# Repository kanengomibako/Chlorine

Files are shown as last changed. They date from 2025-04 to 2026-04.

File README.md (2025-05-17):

# Chlorine
### STM32 Programmable Digital Effects Pedal
STM32マイコンを搭載した、プログラミング可能なデジタルエフェクターです。C言語またはC++で開発を行います。もちろんプログラム書き込み後は単体のエフェクターとして動作可能です。

旧機種 [Sodium](https://github.com/kanengomibako/Sodium) と比較すると、処理能力は2倍以上です。また、最大入出力音量増加・ノイズ低減・操作系強化・USBアップデート機能追加等、大幅にアップグレードされました。

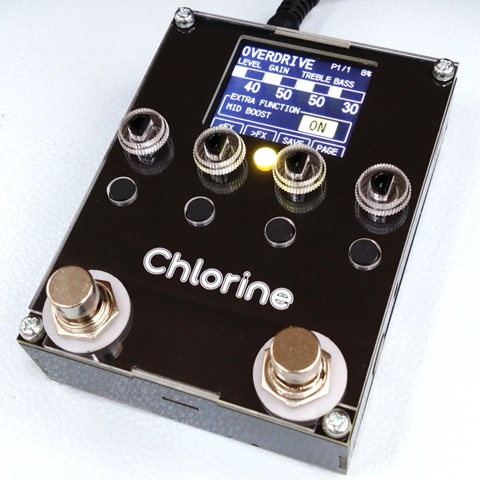
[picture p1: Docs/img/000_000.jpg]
Chlorine_pic


### 別途必要なもの
- DC9V（センターマイナス）出力のACアダプターで、0.5A以上の電流出力が可能なもの
> [!caution]
> 10V以上の電圧で連続使用しないでください。故障の原因となります。

- PC（Windows、macOS、Linux いずれも可、64bit推奨）<br/>※ 32bit環境では使用できる開発ソフトが限られます。
- STM32対応のデバッガ（プログラム書き込みやデバッグを行う機器）<br/>
	→ [デバッガ購入について](https://github.com/kanengomibako/Sodium/blob/main/Docs/005_%E3%83%87%E3%83%90%E3%83%83%E3%82%AC%E8%B3%BC%E5%85%A5%E3%81%AB%E3%81%A4%E3%81%84%E3%81%A6.md)
- PCとデバッガを接続するUSBケーブル
- デバッガとChlorine本体を接続するケーブル<br/>
	→ [コネクタ付コード 3P](https://akizukidenshi.com/catalog/g/gC-15384/) と [両端ロングピンヘッダー](https://akizukidenshi.com/catalog/g/g109055/) 等

### 各部の機能
- INPUT 端子：ギターや他の機器からの出力を接続します（ステレオ入力可）。
- OUTPUT 端子：アンプや他の機器の入力へ接続します（ステレオ出力可）。
- +9VDC 端子：ACアダプターを接続します。
- 各スイッチ・ロータリーエンコーダ：任意の機能をプログラミング可能です。サンプルプログラムの操作については[別ページ](Docs/000_初期プログラムについて.md)をご参照ください。
- MIDI 入力端子：他の機器からのMIDI信号を入力することができます（TRS MIDI）。
- Serial Wire Debug (SWD) 接続ピンソケット：デバッガのSWCLK、GND、SWDIOピンを、Chlorineのピンソケットへそれぞれ接続します。
- USB Type-C 入力端子：USB Type-Cケーブルを接続することができます。

### 資料
- [初期プログラムについて](Docs/000_初期プログラムについて.md)
- [デバッガ購入について](https://github.com/kanengomibako/Sodium/blob/main/Docs/005_%E3%83%87%E3%83%90%E3%83%83%E3%82%AC%E8%B3%BC%E5%85%A5%E3%81%AB%E3%81%A4%E3%81%84%E3%81%A6.md)
- [プログラム書き込み・デバッグ](Docs/001_プログラム書き込み・デバッグ.md)
- [マイコンの機能設定](Docs/003_マイコンの機能設定.md)
- [プログラミング概要](Docs/004_プログラミング概要.md)
- [Chlorine プログラム書込ツール](https://kanengomibako.github.io/pages/00361_Chlorine_WebUSBDFU.html)
- [開発記録](https://kanengomibako.github.io/pages/00364_chlorine.html)

エフェクトについては、旧機種Sodium用のページをご参照ください。基本的にはChlorineも同じプログラム内容です。

- [エフェクト種類管理（fx.cpp）について](https://github.com/kanengomibako/Sodium/blob/main/Docs/100_%E3%82%A8%E3%83%95%E3%82%A7%E3%82%AF%E3%83%88%E7%A8%AE%E9%A1%9E%E7%AE%A1%E7%90%86%EF%BC%88fx.cpp%EF%BC%89%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)

- [エフェクトファイル（fx_○○.hpp）について](https://github.com/kanengomibako/Sodium/blob/main/Docs/110_%E3%82%A8%E3%83%95%E3%82%A7%E3%82%AF%E3%83%88%E3%83%95%E3%82%A1%E3%82%A4%E3%83%AB%EF%BC%88fx_%E2%97%8B%E2%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)

- [各エフェクト説明目次](https://github.com/kanengomibako/Sodium/blob/main/Docs/200_%E5%90%84%E3%82%A8%E3%83%95%E3%82%A7%E3%82%AF%E3%83%88%E8%AA%AC%E6%98%8E%E7%9B%AE%E6%AC%A1.md)

| 主な仕様 |  |
| - | - |
| サンプリング周波数 | 48 kHz（44.1 kHz または 96 kHz に設定可能） |
| 内部演算 | 32 ビット浮動小数点 |
| AD、DA変換 | 24 ビット |
| レイテンシ | 1.2 ミリ秒（サンプルプログラム実行時） |
| 最大入力レベル | 2.0 Vrms (+8.2 dBu) |
| 入力インピーダンス | 1 MΩ |
| 最大出力レベル | 2.0 Vrms (+8.2 dBu) |
| 出力インピーダンス | 1 kΩ |
| バイパス | バッファード・バイパス（バイパス音もAD/DA変換されます） |
| コントロール | 押しボタンスイッチ付きロータリーエンコーダ × 4<br/>押しボタンスイッチ × 4　フットスイッチ × 2 |
| ディスプレイ | 1.77インチ 液晶ディスプレイ　カラー 160 × 128 ドット |
| インジケーター | 3色LED（直径5mm） |
| 接続端子 | INPUT端子　OUTPUT端子　電源入力端子　MIDI入力端子<br/>Serial Wire Debug (SWD) 接続ピンソケット　USB Type-C 入力端子 |
| 消費電流 | 180 mA |
| 外形寸法 | 幅 76 mm × 奥行 100 mm × 高さ 45 mm |
| 質量 | 200 g |

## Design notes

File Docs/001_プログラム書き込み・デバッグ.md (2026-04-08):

# プログラム書き込み、デバッグ

例として、サンプルプログラムの書き込み、デバッグまでの手順を説明します。

***

### 1. STM32CubeIDE、STM32CubeMXのインストール
STM32マイコンの統合開発環境として、[STM32CubeIDE](https://www.st.com/ja/development-tools/stm32cubeide.html)と[STM32CubeMX](https://www.st.com/ja/development-tools/stm32cubemx.html)をインストールします（32bitのOSには非対応）。ダウンロードに[myST](https://www.st.com/content/st_com/ja.html)への登録が必要です。初回起動時にWorkspace（作業フォルダ）を設定しますが、パスに全角文字が入らないようにしておきます。STM32CubeIDE未経験の方は、練習としてNucleo Boardを使ったLチカを先にされておくことをお勧めします。

- 参考ページ → [STM32CubeIDE 2.0.0 workflow tutorial](https://community.st.com/t5/stm32-mcus/stm32cubeide-2-0-0-workflow-tutorial/ta-p/864831)

***

### 2. 必要なファイルのダウンロード、コード出力、ビルド

- 下記URLからzipファイルをダウンロード・展開

  [https://github.com/kanengomibako/Chlorine/blob/main/Src/example/Chlorine_example_v0.2.zip](https://github.com/kanengomibako/Chlorine/blob/main/Src/example/Chlorine_example_v0.2.zip)

- Workspace（作業フォルダ）内に、新しく「Chlorine_example」というフォルダを作成

- Chlorine_example.iocをChlorine_exampleフォルダ内に移動

- STM32CubeMXを起動 → Other Projects から Chlorine_example.iocを読み込み → GENERATE CODE

  ※ バージョンが違うといったメッセージが表示された場合は、「Continue」を選択します。

  ※ 初回はファームウェアのダウンロード等があるため時間がかかります。

- ダウンロード・展開したファイルを移動
	- STM32H723VGTX_FLASH.ld → プロジェクトフォルダ内の同名ファイルに上書き
		
	- .cファイル　.cppファイル → Core/Src フォルダへ（main.c は上書き）
	
	- .hファイル　.hppファイル → Core/Inc フォルダへ
	
- STM32CubeIDEを起動 → File → STM32 Project Create/Import → STM32CubeMX/STM32CubeIDE Projectを選択 → Chlorine_exampleフォルダを選択

- プロジェクトを右クリックし、Convert to C++ → 金槌アイコンをクリックしてビルド

- common.h を編集すると時間設定等を行うことができます。

- fx.cpp を編集すると有効化するエフェクトを選択できます。

***

### 3. デバッガの接続、デバッグ
- デバッガのSWCLK、GND、SWDIOピンを、Chlorine側のピンソケットへそれぞれ接続

  ▼ Nucleo Board（Nucleo-64タイプ）を使う場合（左上のジャンパーを外しておく）

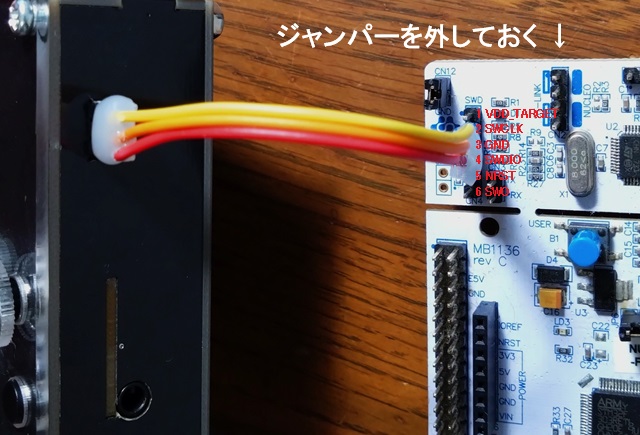
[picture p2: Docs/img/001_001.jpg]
デバッガーの接続
  

- 虫アイコンをクリック → Edit Configuration ウィンドウ → そのままOK

プログラムが書き込まれ、デバッグが開始されます。デバッグ画面では動作開始、一時停止等の操作を行うことができます。

サンプルプログラムの操作方法については、[初期プログラムについて](000_初期プログラムについて.md)のページをご参照ください。

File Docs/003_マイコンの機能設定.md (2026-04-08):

# マイコンの機能設定

iocファイルを開くと、STM32マイコンのピンや機能の設定を行うことができます。Chlorineでの設定内容について説明します。

~~2025年4月7日時点の最新STM32CubeMXソフトウェア（6.14）では、SAIの設定を行うことができません。iocファイルをテキストエディタで開き、「MxCube.Version=6.13.0」「MxDb.Version=DB.6.0.130」と編集すると旧バージョンになります。開くときに新しいバージョンに移行する（Migrate）かダイアログが出るので、旧バージョンのままの Continue を選択します。~~2026年4月8日時点の最新STM32CubeMXソフトウェア（6.17.0）では、修正されています。

***

### 1. System Core
＜キャッシュを有効化、MPUの設定＞
- System Core → CORTEX_M7
	- CPU ICache : Enabled
	- CPU DCache : Enabled
	- MPU Control Mode : Background Region Privileged accesses only + MPU Disabled during ～
	- MPU Region : Enabled
	- MPU Region Base Address : 0x30000000
	- MPU Region Size : 512B
	- MPU SubRegion Disable : 0x0
	- MPU TEX field level : level 0
	- MPU Access Permission : ALL ACCESS PERMITTED
	- MPU Instruction Access : ENABLE
	- MPU Shareability Permission : ENABLE
	- MPU Cacheable Permission : DISABLE
	- MPU Bufferable Permission : ENABLE

＜クロック源として外部水晶振動子を使用、レギュレータの設定＞
- System Core → RCC
	- High Speed Clock (HSE) : Crystal/Ceramic Resonator
	- Parameter Settings タブ
	  - Power Regulator Voltage Scale : Power Regulator Voltage Scale 0

***
### 2. Timers
＜ディスプレイの輝度調整のため、PWMを有効化＞
- Timers → TIM1
  - Channel4 : PWM Generation CH4
  - Parameter Settings タブ Counter Settings
    - Prescaler (PSC - 16 bits value) : 0
    - Counter Period (AutoReload Resister - 16 bits value) : 1023

***

### 3. Connectivity

＜EEPROM接続のため、I2C2を有効化＞

- Connectivity → I2C2
  - I2C : I2C
  - Parameter Settings タブ
    - I2C Speed Mode : Fast Mode
    - I2C Speed Frequency (KHz) : 400
- PB10、PB11 を使うようにピン設定

＜ディスプレイ接続のため、SPI2を有効化＞

- Connectivity → SPI2
  - Mode : Half-Duplex Master
  - Parameter Settings タブ
    - Data Size : 8 Bits
    - Prescaler (for Baud Rate) : 32
- PB13、PB15 を使うようにピン設定

＜MIDI信号送受信のため、USART3を有効化＞

- Connectivity → USART3
  - Mode : Asynchronous
  - Parameter Settings タブ
    - Baud Rate : 31250 Bits/s
    - Stop Bits : 1
    - MSB First : Disable
  - NVIC Settings タブ
    - USART3 global interrupt にチェック
- PD8 、PD9 を使うようにピン設定
- System Core → NVIC（割り込みの優先度を設定）
  - USART3 global interrupt の Preemption Priority : 5

***

### 3. Multimedia 
＜オーディオコーデック接続のため、SAI1を有効化＞
- Multimedia → SAI1
  - SAI A
    - Mode : Master with Master Clock Out
    - I2S/PCM Protocolにチェック
  - SAI B
    - Mode : Synchronous Slave
    - I2S/PCM Protocolにチェック
- Parameter Settings タブ
  - SAI A
    - Audio Mode : Master Receive
    - Data Size : 32 Bits
    - Audio Frequency : 48 KHz
    - Fifo Threshold : Half Full
  - SAI B
    - Audio Mode : Slave Transmit
    - Data Size : 32 Bits
    - Fifo Threshold : Half Full
- DMA Settings タブ
  - Addボタンで追加 → DMA Request [SAI1_A]  Priority [Very High]
    - Mode : Circular
    - Data Width (Peripheral) : Word
    - Data Width (Memory) : Word
  - Addボタンで追加 → DMA Request [SAI1_B]  Priority [Very High]
    - Mode : Circular
    - Data Width (Peripheral) : Word
    - Data Width (Memory) : Word
- PE2、PE3、PE4、PE5、PE6 を使うようにピン設定

***

### 4. Trace and Debug

＜デバッガーの接続方式を設定＞

- Trace and Debug → DEBUG
  - Debug : Serial Wire

***

### 5. Clock Configuration
Clock Configuration タブで下図の通り設定

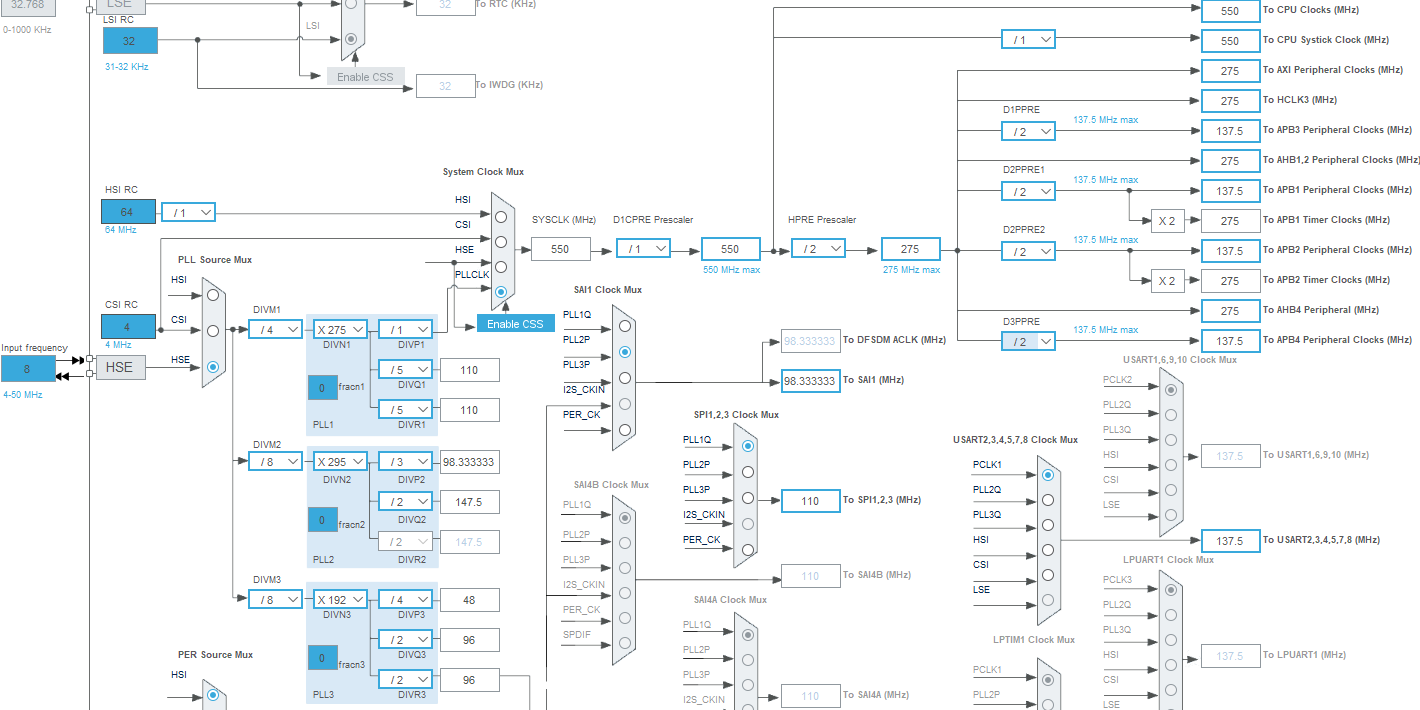
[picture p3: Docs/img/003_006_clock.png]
clock
 

実際のオーディオサンプリングレートは、SAIクロックを2の累乗数で割った数となるため、98.333 MHz ÷ 2048 ＝ 48014.32 Hz です。48kHzから少しズレますが、プログラム上の定義をこの値にすれば実用上問題はありません（#define SAMPLING_FREQ 48014.32f）。

オーディオサンプリングレートを44.1kHzにする場合は、DIVN2とDIVP2を [×271] [/3] とすると誤差が少ないです（90.333 MHz ÷ 2048 ＝ 44108.07 Hz）。

***

### 6. スイッチ・LED（GPIO）
- Pinout viewでGPIO_Input、GPIO_Outputを設定

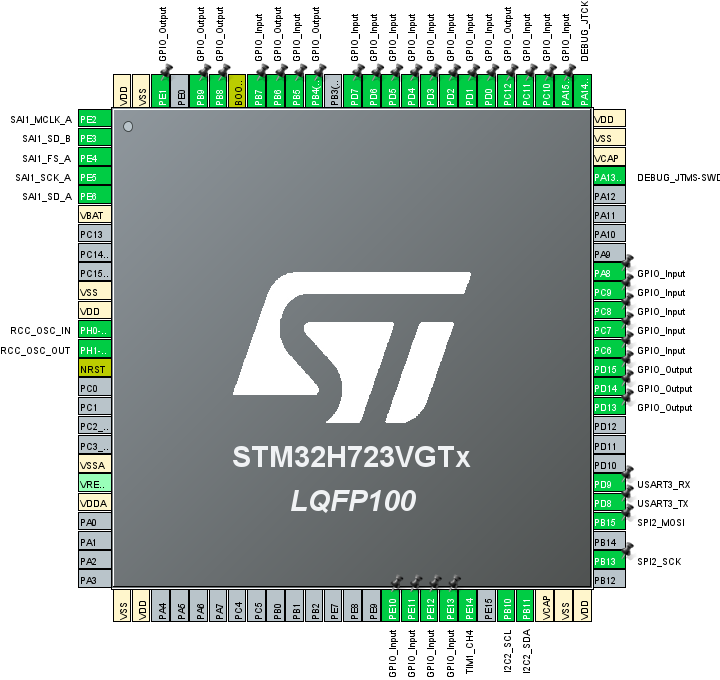
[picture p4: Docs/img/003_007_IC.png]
IC
 

- System Core → GPIO からUser Labelを設定

User Labelの定義は、main.h に自動出力されます。（例：#define LED_B_Pin GPIO_PIN_12）

| ピン | ユーザーラベル |
| ---- | ---- |
| PA8 | RE2A |
| PA15 | RE2B |
| PB4 | LED_G |
| PB5 | RE0A |
| PB6 | LED_R |
| PB7 | RE0B |
| PB8 | M0 |
| PB9 | M1 |
| PC6 | SW9 |
| PC7 | RE3B |
| PC8 | SW3 |
| PC9 | RE3A |
| PC10 | SW5 |
| PC11 | SW4 |
| PC12 | LED_B |
| PD0 | SW2 |
| PD1 | SW8 |
| PD2 | SW1 |
| PD3 | RE1A |
| PD4 | SW7 |
| PD5 | RE1B |
| PD6 | SW6 |
| PD7 | SW0 |
| PD13 | LCD_RS |
| PD14 | LCD_RES |
| PD15 | LCD_CS |
| PE1 | CODEC_RST |
| PE10 | HARDWARE_VERSION0 |
| PE11 | HARDWARE_VERSION1 |
| PE12 | HARDWARE_VERSION2 |
| PE13 | HARDWARE_VERSION3 |

***

### 7. 最適化設定

高速動作のため、コンパイラの最適化設定を変更します。iocファイルの編集ではなく、メニューバーから設定します。
- Project → Properties → C/C++ Build → Settings → Tool Settings タブ
	- C言語
		- MCU GCC Compiler → Optimization → Optimization level [Optimize Most (-O3)]
	- C++
		- MCU G++ Compiler → Optimization → Optimization level [Optimize Most (-O3)]

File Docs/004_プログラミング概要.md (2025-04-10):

# プログラミング概要

### 1. ハードウェア
Chlorineの回路を簡略化した図を示します。

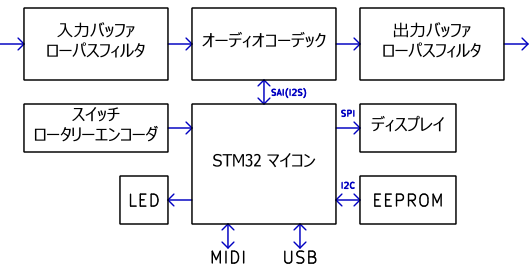
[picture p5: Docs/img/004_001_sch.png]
簡略図
 

入力信号は、オーディオコーデックでアナログ→デジタル変換され（ADC）、マイコンへ送られます。マイコンで信号処理し送られたデータは、デジタル→アナログ変換され（DAC）出力されます。このデータ送受信の方式は I2S（Inter-IC Sound）フォーマットと呼ばれるもので、この通信を行うのが SAI ペリフェラルです。

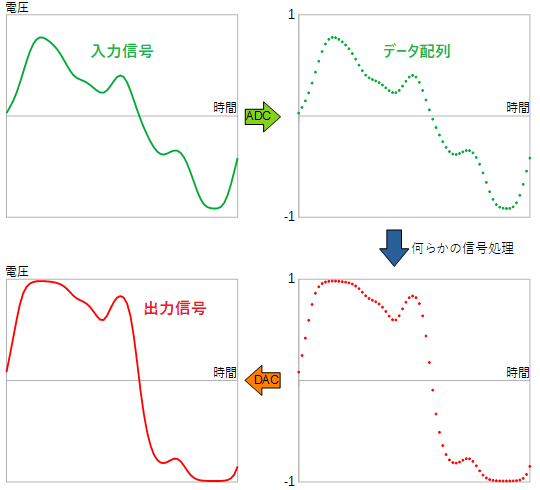
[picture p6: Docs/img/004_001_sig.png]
波形
 

機器に入力された音声信号は時間と電圧の関係として表されます。これを一定時間ごとにサンプリング（電圧読み取り）し、データ配列としてコンピュータに取り込みます。このサンプルデータに何らかの処理を施すことで、エフェクトをかけるということになります。

オーディオサンプリングレート44.1kHzの場合は、1秒間に44100個<sup>※</sup>のデータサンプルを送受信します。効率よく処理するため、ある程度まとまったサンプル数で処理を行います。このサンプルの個数がブロックサイズです。（※ 正確には、LchとRchで1組として44100組、88200個）

マイコンからディスプレイへのデータ送信はSPI（Serial Peripheral Interface）、EEPROMのデータ保存・読込はI2C（Inter-Integrated Circuit）と呼ばれる通信方式です。

***

### 2. 動作の流れ

- メインループ
	
	まず main.c の main 関数が実行されますが、その中で各機能の初期化後、mainLoop 関数が繰り返し実行されます。Chlorineでは、ここで主にディスプレイ表示の更新を行っています。
	※ main.c に直接主なコードを書いてもよいのですが、誤って USER CODE 以外の部分に書いてしまうとコード自動生成時に消去されるので、user_main.cpp という別ファイルに分けています。
	
- SAI 割り込み
	
	SAI で常にデータの入出力を行っていますが、ブロックサイズごとに割り込みが起こるようになっています（3. 信号処理詳細 参照）。この割り込み時にエフェクト処理やスイッチ状態の読み取りを行っています。

メインループ 

デュアルコアではないので、同時並行して処理を進めることはできません。基本は信号処理（割り込み）を行い、空いた時間にメインループの処理が進みます。もし信号処理に時間がかかりすぎれば、メインループ側の処理が進まないのでディスプレイ表示の更新がうまくいかないことになります。

***

### 3. 信号処理詳細

SAI用の送受信バッファ配列サイズはブロックサイズの4倍となっています。中身は「Lch前半・後半、Rch前半・後半」で、データの順序はLR交互（L・R・L・R...）ですが、ここではLRで1組として考えます。

データ前半の受信が終わると user_main.cpp にある HAL_SAI_RxHalfCpltCallback 関数が、後半の受信が終わると HAL_SAI_RxCpltCallback 関数が呼び出されます。下図のような流れです。

SAI 

例えば音量を上げるエフェクトの場合は、この割り込み内でデータ数値を増加させればいいということになります。

割り込みの間隔は、ブロックサイズ16、サンプリングレート48kHzの場合 16 / 48 = 0.33 ms（ミリ秒）です。処理遅延はこの2倍発生し、さらにオーディオコーデックIC自体の遅延があるため、全体の遅延（レイテンシ）は約1.2msとなっています。

- DMAについて

  DMA（Direct Memory Access）はデータ送受信の繰り返しを自動で行ってくれる便利な機能です。ただしSTM32H7では、DMA対象データの配置先の指定、MPU（Memory Protection Unit）の設定が必要となります。
  
  - 参考ページ → [STM32H7でキャッシュ一貫性を保持したDMA転送(Memory-to-Peripheral)](https://www.keshikan.net/gohantabeyo/?p=563)
  
    ※ MPUの設定は、[マイコンの機能設定](003_マイコンの機能設定.md)で行うことが可能です。

***

### 4. スイッチ

前述の通り、SAI 割り込みは定期的に起こります。スイッチが押されているかどうかの読み取り（HAL_GPIO_ReadPin 関数）も割り込み内で行います。

読み取りはそこまで頻繁に行う必要はないため、割り込み1では左端スイッチ、割り込み2では中央左スイッチ...というように読み取るスイッチを順番に入れ替えています。（フットスイッチはタップテンポの精度に関係してくるため、毎回読み取りを行っています。）

スイッチのチャタリングによる誤検出防止のため、一定時間連続で押されている判定があった場合に処理を行います。判定時間は #define SHORT_PUSH_MSEC 20 といった具合に設定しています。

***

### 5. ロータリーエンコーダ

一般にロータリーエンコーダの出力波形は下図のようになります。

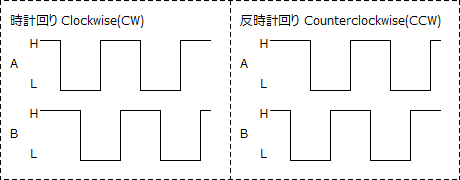
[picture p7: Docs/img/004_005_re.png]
RE


SAI 割り込みのときにHとLを読み取り、4パターンで記録しておきます。

- A: H　B: H → パターン0
- A: L　B: H → パターン1
- A: L　B: L → パターン2
- A: H　B: L → パターン3

そして、前回のパターンから現在のパターンへの変化によって時計回りと反時計回りを判定します。

※ ロータリーエンコーダの種類によってはクリック位置での出力規定が異なるため、別の判定へと修正が必要となる場合があります。

- パターン0からパターン1 または パターン2からパターン3 :  時計回り
- パターン0からパターン3 または パターン2からパターン1 :  反時計回り

***

### 6. データ保存

USBアップデートでフラッシュメモリを書き換えるとなると、ユーザーデータを外部に保存しておく必要があります。そのため、Chlorineでは外部EEPROMを使用しています。データ保存は優先度を高くする必要がないため、メインループ内で処理を行っています。EEPROMは100万回以上書き換えできますが、プログラミングのミスで繰り返し書き込みが発生するような状態が起きると寿命が縮まってしまうため、注意が必要です。

***

### 7. MIDI

MIDIメッセージの受信時に割り込み（HAL_UART_RxCpltCallback 関数）が発生しますが、現状は特に機能を持たせていません。

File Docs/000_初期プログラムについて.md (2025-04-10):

# 初期プログラムについて

動作確認用初期プログラムとして、数種類のエフェクトを切り替えて実行可能なサンプルプログラムが入っています。

### 表示

- 最上部

  エフェクト名、パラメータページ番号／最大パラメータページ数、CPU使用率%

  ※入出力が過大な音量でクリッピングが起きたとき、「L R i o」といった文字が点滅表示されます。それぞれ「左 右 入力 出力」という意味です。

- 中段上

  エフェクトパラメータ名と数値

- 中段下

  右フットスイッチに割り当てられている機能の表示

- 下段

  押しボタンスイッチに割り当てられている機能の表示

### 操作方法
- スイッチ付きロータリーエンコーダ（ノブを押すとスイッチとして動作）
	- ロータリーエンコーダを回転：パラメータの増減
	
	- スイッチを押しながらロータリーエンコーダを回転：パラメータ10ずつ増減（パラメータ数値に下線が表示）

- 左端スイッチ：前エフェクトに切替

- 中央左スイッチ：次エフェクトに切替

- 中央右スイッチ：データ保存（右上に「STORED!」と点滅表示）

- 右端スイッチ：エフェクトパラメータが5つ以上の場合、ページ切替

- 左フットスイッチ：エフェクトのオン／オフ切替

- 右フットスイッチ：ブースト機能のオン／オフ切替 または タップテンポ

### 輝度調整
右フットスイッチを押した状態で起動すると、画面の輝度（Brightness）が設定できます。起動後も右フットスイッチを押したまま、右端スイッチと左端スイッチで調整します。右フットスイッチを離すと、自動で輝度データが保存されます。

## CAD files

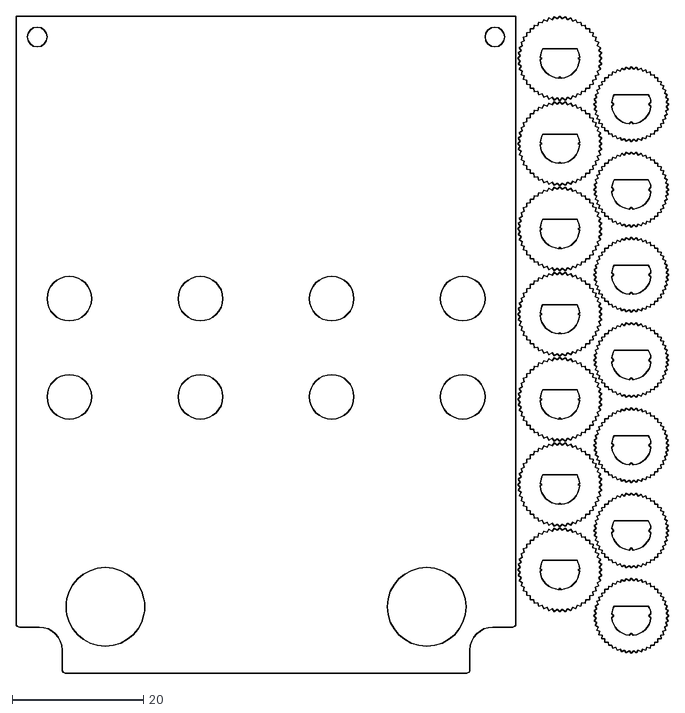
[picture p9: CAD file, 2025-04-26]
KiCad/enclosure/chlorineBox-acryl-Edge_Cuts.dxf
99.5 x 100.2

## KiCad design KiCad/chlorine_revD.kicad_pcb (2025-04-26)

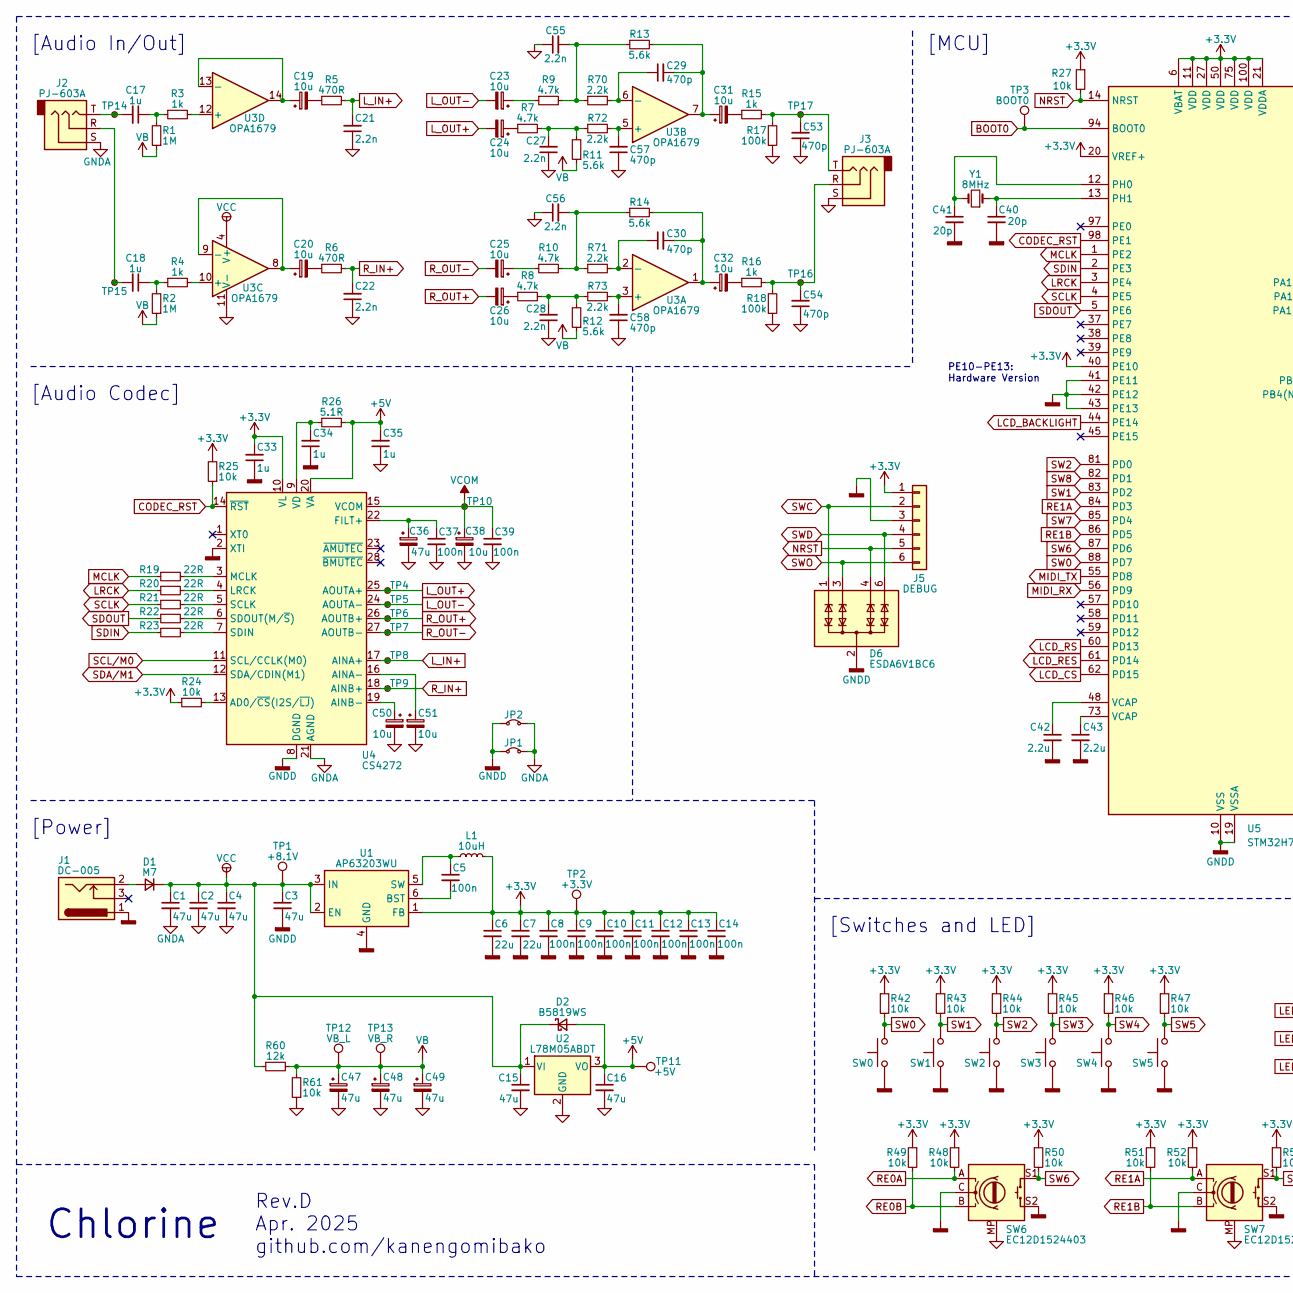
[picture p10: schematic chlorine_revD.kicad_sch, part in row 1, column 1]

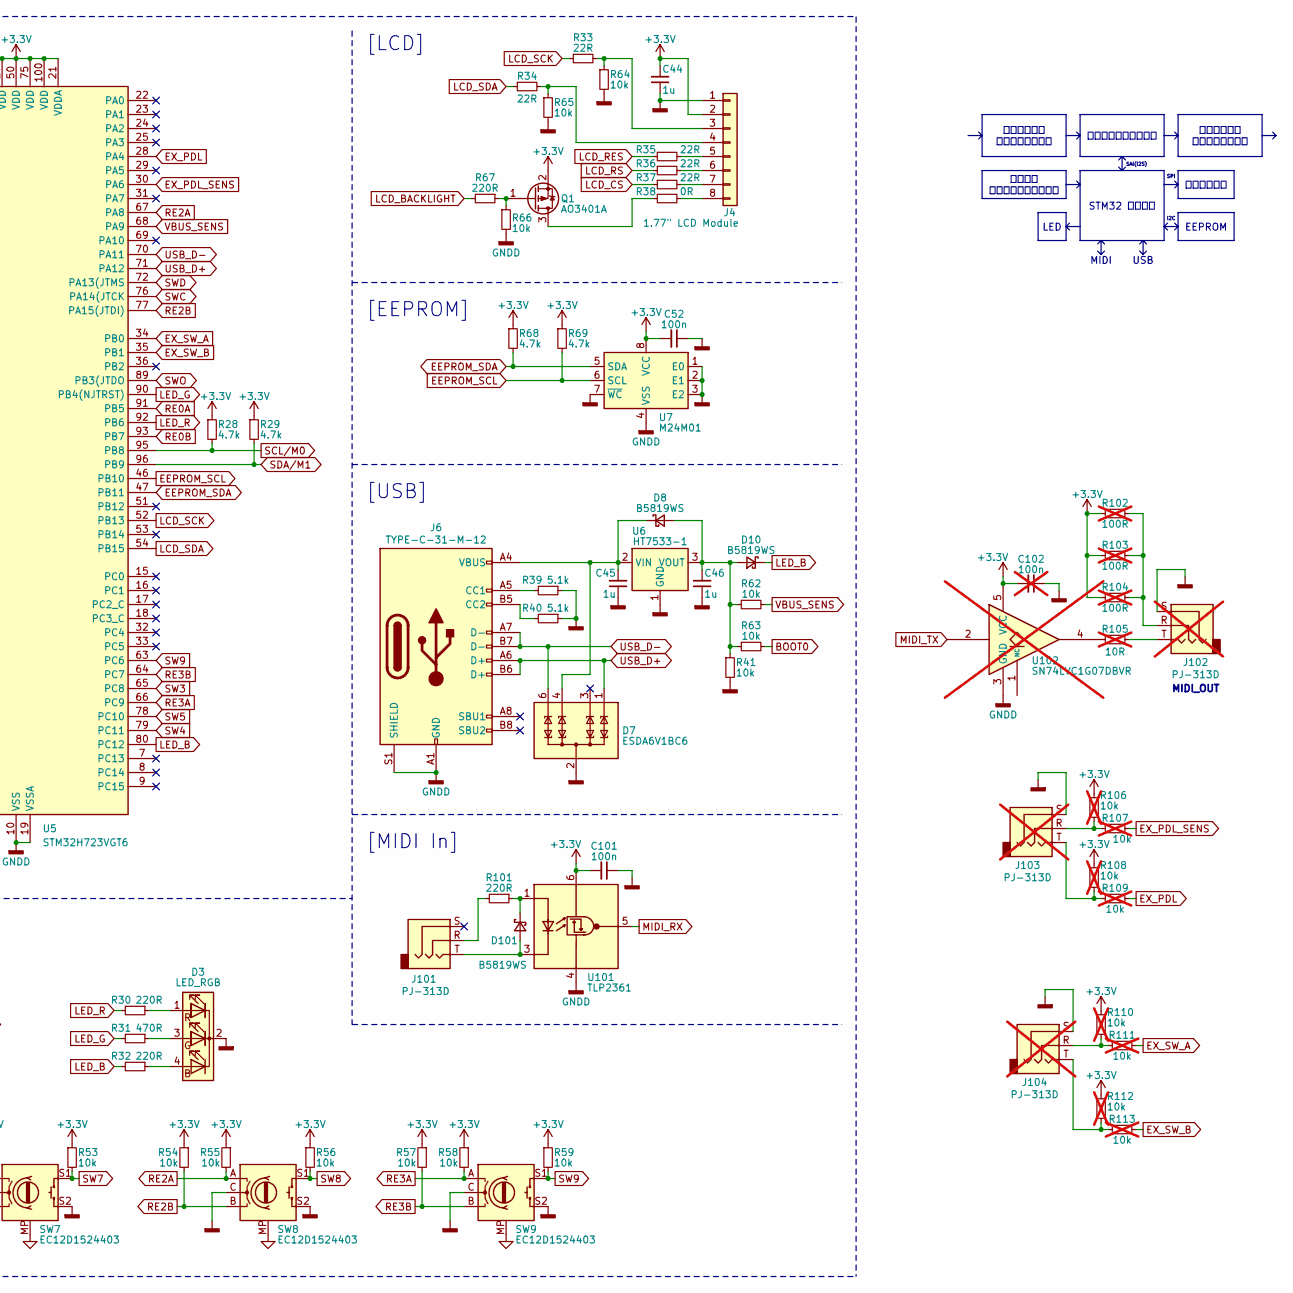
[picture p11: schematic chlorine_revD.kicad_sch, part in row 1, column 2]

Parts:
C1, C2, C3, C4, C15, C16: 47u; C_1206_3216Metric; MPN C96123
C5, C8, C9, C10, C11, C12, C13, C14, C37, C39, C52, C101: 100n; C_0603_1608Metric; MPN C14663
C6, C7: 22u; C_1206_3216Metric; MPN C12891
C17, C18: 1u; C_1210_3225Metric; MPN C569895
C19, C20, C23, C24, C25, C26, C31, C32, C38, C50, C51: 10u; CP_EIA-3216-10_Kemet-I; MPN C7171
C21, C22, C27, C28, C55, C56: 2.2n; C_0805_2012Metric; MPN C28260
C29, C30, C53, C54, C57, C58: 470p; C_0603_1608Metric; MPN C85979
C33, C34, C35, C44, C45, C46: 1u; C_0603_1608Metric; MPN C15849
C36, C47, C48, C49: 47u; CP_EIA-3528-15_AVX-H; MPN C22036
C40, C41: 20p; C_0603_1608Metric; MPN C1648
C42, C43: 2.2u; C_1206_3216Metric; MPN C50254
C102: 100n; C_0603_1608Metric; MPN C14663; not fitted
D1: M7; D_SMA; MPN C95872
D2, D8, D10, D101: B5819WS; my_D_SOD-323; MPN C64886
D3: LED_RGB; my_LED_5mm_RGB_mirror
D6, D7: ESDA6V1BC6; my_SOT-23-6_rotate; MPN C2912546
J1: DC-005; my_DC_Jack
J2, J3: PJ-603A; MPN C309273
J4: 1.77" LCD Module; LCD_Display_1.77inch
J5: DEBUG; PinSocket_1x06_P2.54mm_Horizontal
J6: TYPE-C-31-M-12; USB_C_TYPE-C-31-M-12; MPN C165948
J101: PJ-313D; PJ-313D_HOOYA; MPN C668608
J102, J103, J104: PJ-313D; PJ-313D_HOOYA; MPN C668608; not fitted
JP1, JP2: JP; AD_GND_Jumper
L1: 10uH; L_7.3x7.3_H3.5; MPN C2827354
Q1: AO3401A; SOT-23_rotate; MPN C15127
R1, R2: 1M; R_0603_1608Metric; MPN C22935
R3, R4, R15, R16: 1k; R_0603_1608Metric; MPN C21190
R5, R6, R31: 470R; R_0603_1608Metric; MPN C23179
R7, R8, R9, R10, R28, R29, R68, R69: 4.7k; R_0603_1608Metric; MPN C23162
R11, R12, R13, R14: 5.6k; R_0603_1608Metric; MPN C23189
R17, R18: 100k; R_0603_1608Metric; MPN C25803
R19, R20, R21, R22, R23, R33, R34, R35, R36, R37: 22R; R_0603_1608Metric; MPN C23345
R24, R25, R27, R41, R42, R43, R44, R45, R46, R47, R48, R49, R50, R51, R52, R53, R54, R55, R56, R57, R58, R59, R61, R62, R63, R64, R65, R66: 10k; R_0603_1608Metric; MPN C25804
R26: 5.1R; R_0603_1608Metric; MPN C25197
R30, R32, R67, R101: 220R; R_0603_1608Metric; MPN C22962
R38: 0R; R_1206_3216Metric; MPN C17888
R39, R40: 5.1k; R_0603_1608Metric; MPN C23186
R60: 12k; R_0603_1608Metric; MPN C22790
R70, R71, R72, R73: 2.2k; R_0603_1608Metric; MPN C4190
R102, R103, R104: 100R; R_1206_3216Metric; MPN C17901; not fitted
R105: 10R; R_1206_3216Metric; MPN C17903; not fitted
R106, R107, R108, R109, R110, R111, R112, R113: 10k; R_0603_1608Metric; MPN C25804; not fitted
SW0: SW0; my_SW_PUSH_12mm_narrow
SW1: SW1; my_SW_PUSH_12mm_narrow
SW2: SW2; my_SW_PUSH_12mm_narrow
SW3: SW3; my_SW_PUSH_12mm_narrow
SW4: SW4; spst_momentary_sw_foot
SW5: SW5; spst_momentary_sw_foot
SW6, SW7, SW8, SW9: EC12D1524403
TP1: +8.1V; my_TestPoint_1.2mm
TP2: +3.3V; my_TestPoint_1.2mm
TP3: BOOT0; my_TestPoint_1.2mm
TP4: L_OUT+; my_TestPoint_1.2mm
TP5: L_OUT-; my_TestPoint_1.2mm
TP6: R_OUT+; my_TestPoint_1.2mm
TP7: R_OUT-; my_TestPoint_1.2mm
TP8: L_IN+; my_TestPoint_1.2mm
TP9: R_IN+; my_TestPoint_1.2mm
TP10: VCOM; my_TestPoint_1.2mm
TP11: +5V; my_TestPoint_1.2mm
TP12: VB_L; my_TestPoint_1.2mm
TP13: VB_R; my_TestPoint_1.2mm
TP14: L_IN; my_TestPoint_1.2mm
TP15: R_IN; my_TestPoint_1.2mm
TP16: R_OUT; my_TestPoint_1.2mm
TP17: L_OUT; my_TestPoint_1.2mm
U1: AP63203WU; my_SOT-23-6_rotate; MPN C780769
U2: L78M05ABDT; my_DPAK_TO-252-2; MPN C58069
U3: OPA1679; TSSOP-14_4.4x5mm_P0.65mm_rotate; MPN C2057264
U4: CS4272; TSSOP-28_4.4x9.7mm_P0.65mm_rotate
U5: STM32H723VGT6; LQFP-100_14x14mm_P0.5mm_rotate
U6: HT7533-1; SOT-89-3-rotate; MPN C14289
U7: M24M01; SOIC-8_3.9x4.9mm_P1.27mm_rotate
U101: TLP2361; SO-5_4.4x3.6mm_P1.27mm_rotate; MPN C107626
U102: SN74LVC1G07DBVR; my_SOT-23-5_rotate; MPN C7394020; not fitted
Y1: 8MHz; Crystal_SMD_5032-2Pin_5.0x3.2mm; MPN C115962

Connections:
+3.3V: C6.1, C7.1, C8.1, C9.1, C10.1, C11.1, C12.1, C13.1, C14.1, C33.2, C44.2, C52.2, C101.2, C102.2, J4.2, J5.1, L1.2, Q1.2 (S), R24.1, R25.2, R27.1, R28.1, R29.1, R42.1, R43.1, R44.1, R45.1, R46.1, R47.1, R48.1, R49.1, R50.1, R51.1, R52.1, R53.1, R54.1, R55.1, R56.1, R57.1, R58.1, R59.1, R68.1, R69.1, R102.2, R103.2, R104.2, R106.1, R108.1, R110.1, R112.1, TP2.1, U1.1 (FB), U4.10 (VL), U5.6 (VBAT), U5.11 (VDD), U5.20 (VREF+), U5.21 (VDDA), U5.27 (VDD), U5.40 (PE10), U5.50 (VDD), U5.75 (VDD), U5.100 (VDD), U7.8 (VCC), U101.6 (VDD), U102.5 (VCC)
+5V: C16.1, C35.2, D2.2 (A), R26.2, TP11.1, U2.3 (VO), U4.20 (VA)
BOOT0: R63.2, TP3.1, U5.94 (BOOT0)
CODEC_RST: R25.1, U4.14 (~RST), U5.98 (PE1)
EEPROM_SCL: R69.2, U5.46 (PB10), U7.6 (SCL)
EEPROM_SDA: R68.2, U5.47 (PB11), U7.5 (SDA)
EX_PDL: R109.2, U5.28 (PA4)
EX_PDL_SENS: R107.2, U5.30 (PA6)
EX_SW_A: R111.2, U5.34 (PB0)
EX_SW_B: R113.2, U5.35 (PB1)
GNDA: C1.2, C2.2, C4.2, C15.2, C16.2, C21.1, C22.1, C27.1, C28.1, C35.1, C36.2, C37.2, C38.2, C39.2, C47.2, C48.2, C49.2, C50.2, C51.2, C53.1, C54.1, C55.1, C56.1, C57.1, C58.1, J2.S, J3.S, JP1.2 (B), JP2.2 (B), R17.1, R18.1, R61.1, SW6.MP, SW7.MP, SW8.MP, SW9.MP, U2.2 (GND), U3.11 (V-), U4.21 (AGND); also elsewhere on the board
GNDD: C3.2, C6.2, C7.2, C8.2, C9.2, C10.2, C11.2, C12.2, C13.2, C14.2, C33.1, C34.1, C40.2, C41.2, C42.2, C43.2, C44.1, C45.1, C46.1, C52.1, C101.1, C102.1, D3.2 (K), D6.2 (COM), D6.5 (COM), D7.2 (COM), D7.5 (COM), J1.1, J4.1, J5.3, J6.A1 (GND), J6.A12 (GND), J6.B1 (GND), J6.B12 (GND), J6.S1 (SHIELD), J102.S, J103.S, J104.S, JP1.1 (A), JP2.1 (A), R39.1, R40.1, R41.2, R64.2, R65.2, R66.2, SW0.1, SW1.1, SW2.1, SW3.1, SW4.1, SW5.1, SW6.C, SW6.S2, SW7.C, SW7.S2, SW8.C, SW8.S2, SW9.C, SW9.S2, U1.4 (GND), U4.2 (XTI), U4.8 (DGND), U5.10 (VSS), U5.19 (VSSA), U5.26 (VSS), U5.41 (PE11), U5.42 (PE12), U5.43 (PE13), U5.49 (VSS), U5.74 (VSS), U5.99 (VSS), U6.1 (GND), U7.1 (E0), U7.2 (E1), U7.3 (E2), U7.4 (VSS), U7.7 (~WC), U101.4 (GND), U102.3 (GND)
LCD_BACKLIGHT: R67.2, U5.44 (PE14)
LCD_CS: R37.1, U5.62 (PD15)
LCD_RES: R35.1, U5.61 (PD14)
LCD_RS: R36.1, U5.60 (PD13)
LCD_SCK: R33.1, U5.52 (PB13)
LCD_SDA: R34.1, U5.54 (PB15)
LED_B: D10.1 (K), R32.2, U5.80 (PC12)
LED_G: R31.2, U5.90 (PB4(NJTRST))
LED_R: R30.2, U5.92 (PB6)
LRCK: R20.1, U5.3 (PE4)
L_IN+: C21.2, R5.2, TP8.1, U4.17 (AINA+)
L_OUT+: C24.2, TP4.1, U4.25 (AOUTA+)
L_OUT-: C23.2, TP5.1, U4.24 (AOUTA-)
MCLK: R19.1, U5.1 (PE2)
MIDI_RX: U5.56 (PD9), U101.5 (VO)
MIDI_TX: U5.55 (PD8), U102.2
NRST: D6.4 (TVS3), J5.5, R27.2, U5.14 (NRST)
unnamed: C17.1, R1.2, R3.1
unnamed: C17.2, J2.T, TP14.1
unnamed: C18.1, R2.2, R4.1
unnamed: C18.2, J2.R, TP15.1
unnamed: C19.2, R5.1
unnamed: C20.2, R6.1
unnamed: C23.1, R9.1
unnamed: C24.1, R7.1
unnamed: C25.1, R10.1
unnamed: C26.1, R8.1
unnamed: C27.2, R7.2, R11.2, R72.1
unnamed: C28.2, R8.2, R12.2, R73.1
unnamed: C29.2, C31.1, R13.2, U3.7
unnamed: C30.2, C32.1, R14.2, U3.1
unnamed: C31.2, R15.1
unnamed: C32.2, R16.1
unnamed: C42.1, U5.48 (VCAP)
unnamed: C43.1, U5.73 (VCAP)
unnamed: C53.2, J3.T, R15.2, R17.2, TP17.1
unnamed: C54.2, J3.R, R16.2, R18.2, TP16.1
unnamed: C55.2, R9.2, R13.1, R70.1
unnamed: C56.2, R10.2, R14.1, R71.1
unnamed: D1.2 (A), J1.2
unnamed: D3.4 (BA), R32.1
unnamed: D3.3 (GA), R31.1
unnamed: D3.1 (RA), R30.1
unnamed: C45.2, D7.4 (TVS3), D8.1 (K), J6.A4 (VBUS), J6.A9 (VBUS), J6.B4 (VBUS), J6.B9 (VBUS), U6.2 (VIN)
unnamed: C46.2, D8.2 (A), D10.2 (A), R41.1, R62.1, R63.1, U6.3 (VOUT)
unnamed: D101.2 (A), J101.T, U101.3 (K)
unnamed: D101.1 (K), R101.1, U101.1 (A)
unnamed: J4.3, R33.2, R64.1
unnamed: J4.4, R34.2, R65.1
unnamed: J4.5, R35.2
unnamed: J4.6, R36.2
unnamed: J4.7, R37.2
unnamed: J4.8, R38.2
unnamed: J6.A5 (CC1), R39.2
unnamed: J6.B5 (CC2), R40.2
unnamed: J101.R, R101.2
unnamed: J102.R, R102.1, R103.1, R104.1
unnamed: J102.T, R105.1
unnamed: J103.R, R106.2, R107.1
unnamed: J103.T, R108.2, R109.1
unnamed: J104.R, R110.2, R111.1
unnamed: J104.T, R112.2, R113.1
unnamed: Q1.3 (D), R38.1
unnamed: Q1.1 (G), R66.1, R67.1
unnamed: R105.2, U102.4
unnamed: C5.2, U1.6 (BST)
unnamed: C5.1, L1.1, U1.5 (SW)
unnamed: C58.2, R73.2, U3.3 (+)
unnamed: C30.1, R71.2, U3.2 (-)
unnamed: C57.2, R72.2, U3.5 (+)
unnamed: C29.1, R70.2, U3.6 (-)
unnamed: R4.2, U3.10 (+)
unnamed: C20.1, U3.8, U3.9 (-)
unnamed: R3.2, U3.12 (+)
unnamed: C19.1, U3.13 (-), U3.14
unnamed: R24.2, U4.13 (AD0/~CS(I2S/~LJ))
unnamed: C51.1, U4.16 (AINA-)
unnamed: C50.1, U4.19 (AINB-)
unnamed: C36.1, C37.1, U4.22 (FILT+)
unnamed: R20.2, U4.4 (LRCK)
unnamed: R19.2, U4.3 (MCLK)
unnamed: R21.2, U4.5 (SCLK)
unnamed: R23.2, U4.7 (SDIN)
unnamed: R22.2, U4.6 (SDOUT(M/~S))
unnamed: C34.2, R26.1, U4.9 (VD)
unnamed: C41.1, U5.12 (PH0), Y1.2
unnamed: C40.1, U5.13 (PH1), Y1.1
RE0A: R48.2, SW6.A, U5.91 (PB5)
RE0B: R49.2, SW6.B, U5.93 (PB7)
RE1A: R52.2, SW7.A, U5.84 (PD3)
RE1B: R51.2, SW7.B, U5.86 (PD5)
RE2A: R55.2, SW8.A, U5.67 (PA8)
RE2B: R54.2, SW8.B, U5.77 (PA15(JTDI))
RE3A: R58.2, SW9.A, U5.66 (PC9)
RE3B: R57.2, SW9.B, U5.64 (PC7)
R_IN+: C22.2, R6.2, TP9.1, U4.18 (AINB+)
R_OUT+: C26.2, TP6.1, U4.26 (AOUTB+)
R_OUT-: C25.2, TP7.1, U4.27 (AOUTB-)
SCLK: R21.1, U5.4 (PE5)
SCL/M0: R28.2, U4.11 (SCL/CCLK(M0)), U5.95 (PB8)
SDA/M1: R29.2, U4.12 (SDA/CDIN(M1)), U5.96 (PB9)
SDIN: R23.1, U5.2 (PE3)
SDOUT: R22.1, U5.5 (PE6)
SW0: R42.2, SW0.2, U5.88 (PD7)
SW1: R43.2, SW1.2, U5.83 (PD2)
SW2: R44.2, SW2.2, U5.81 (PD0)
SW3: R45.2, SW3.2, U5.65 (PC8)
SW4: R46.2, SW4.2, U5.79 (PC11)
SW5: R47.2, SW5.2, U5.78 (PC10)
SW6: R50.2, SW6.S1, U5.87 (PD6)
SW7: R53.2, SW7.S1, U5.85 (PD4)
SW8: R56.2, SW8.S1, U5.82 (PD1)
SW9: R59.2, SW9.S1, U5.63 (PC6)
SWC: D6.1 (TVS1), J5.2, U5.76 (PA14(JTCK)
SWD: D6.6 (TVS4), J5.4, U5.72 (PA13(JTMS)
SWO: D6.3 (TVS2), J5.6, U5.89 (PB3(JTDO)
USB_D+: D7.1 (TVS1), J6.A6 (D+), J6.B6 (D+), U5.71 (PA12)
USB_D-: D7.6 (TVS4), J6.A7 (D-), J6.B7 (D-), U5.70 (PA11)
VB: C47.1, C48.1, C49.1, R1.1, R2.1, R11.1, R12.1, R60.2, R61.2, TP12.1, TP13.1
VBUS_SENS: R62.2, U5.68 (PA9)
VCC: C1.1, C2.1, C3.1, C4.1, C15.1, D1.1 (K), D2.1 (K), R60.1, TP1.1, U1.2 (EN), U1.3 (IN), U2.1 (VI), U3.4 (V+)
VCOM: C38.1, C39.1, TP10.1, U4.15 (VCOM)

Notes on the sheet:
[Power]
I2C
Chlorine
[MIDI In]
MIDI_OUT
SAI(I2S)
出力バッファ ローパスフィルタ
STM32 マイコン
[LCD]
オーディオコーデック
EEPROM
LED
Rev.D Apr. 2025 github.com/kanengomibako
スイッチ ロータリーエンコーダ
ディスプレイ
[Switches and LED]
SPI
USB
[MCU]
MIDI
入力バッファ ローパスフィルタ
[EEPROM]
[Audio In/Out]
[Audio Codec]
[USB]
PE10-PE13: Hardware Version

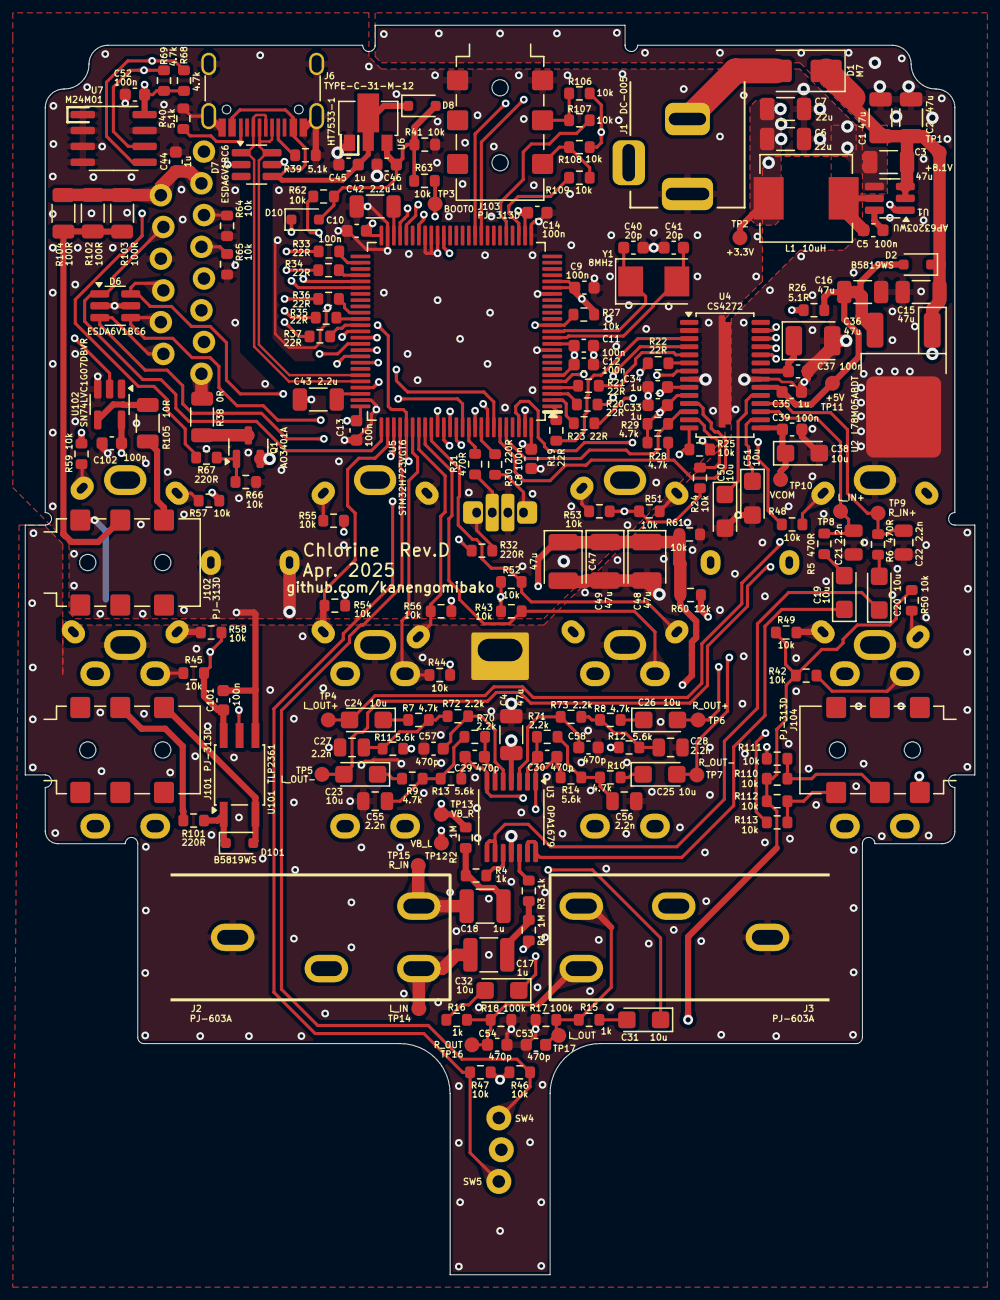
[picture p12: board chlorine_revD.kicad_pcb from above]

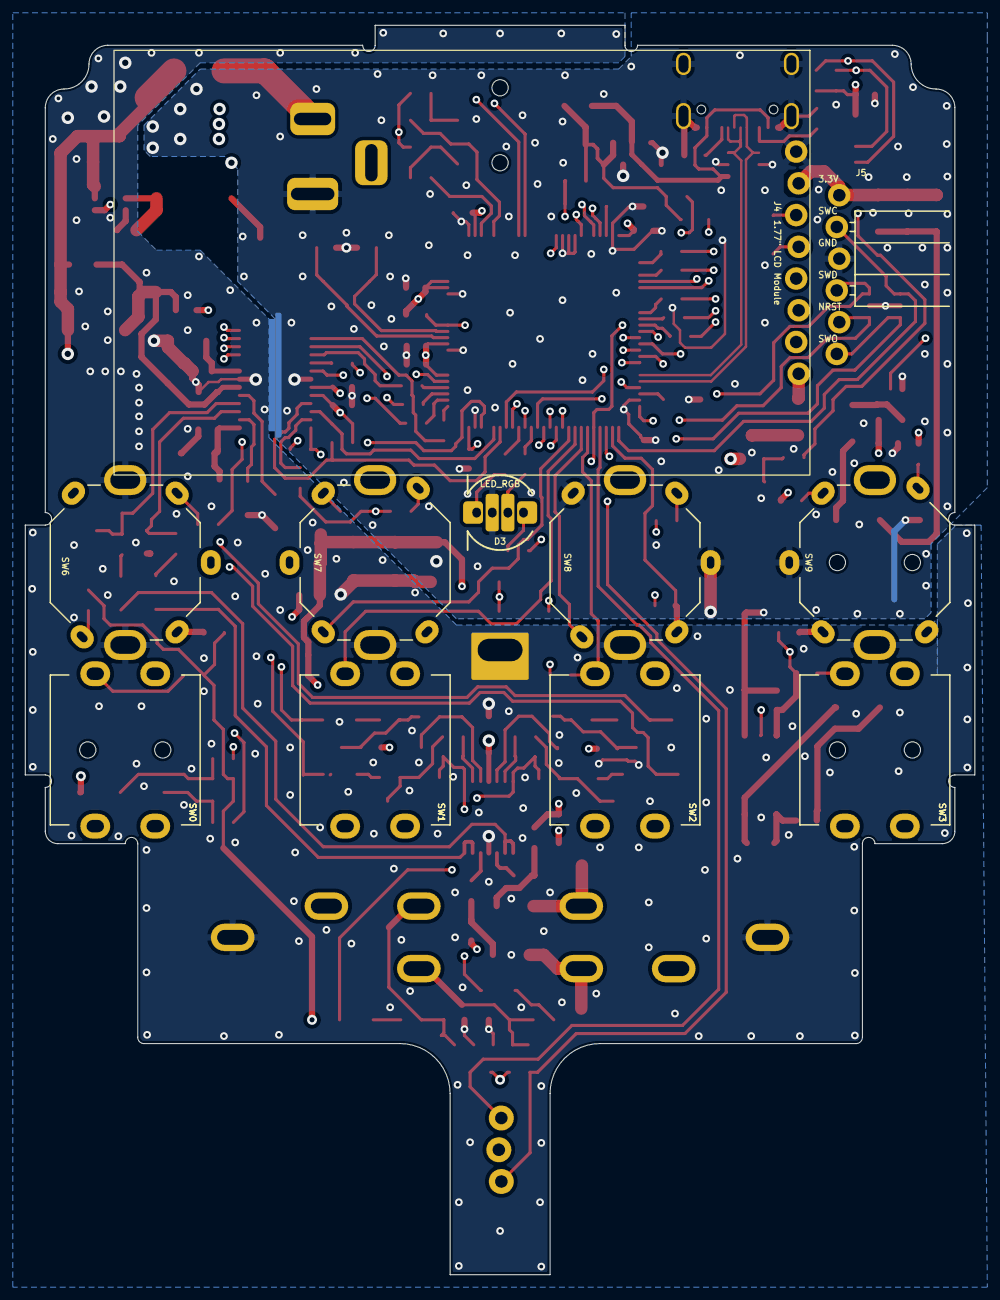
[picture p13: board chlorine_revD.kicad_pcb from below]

Board: 4 copper layers, 76.0 x 100.0 mm, 206 parts (12 on the bottom side), 134 nets.

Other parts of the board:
*: m; MountingHole_3.2mm_M3_ISO7380_Pad

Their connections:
GNDA: *.1; also elsewhere on the board

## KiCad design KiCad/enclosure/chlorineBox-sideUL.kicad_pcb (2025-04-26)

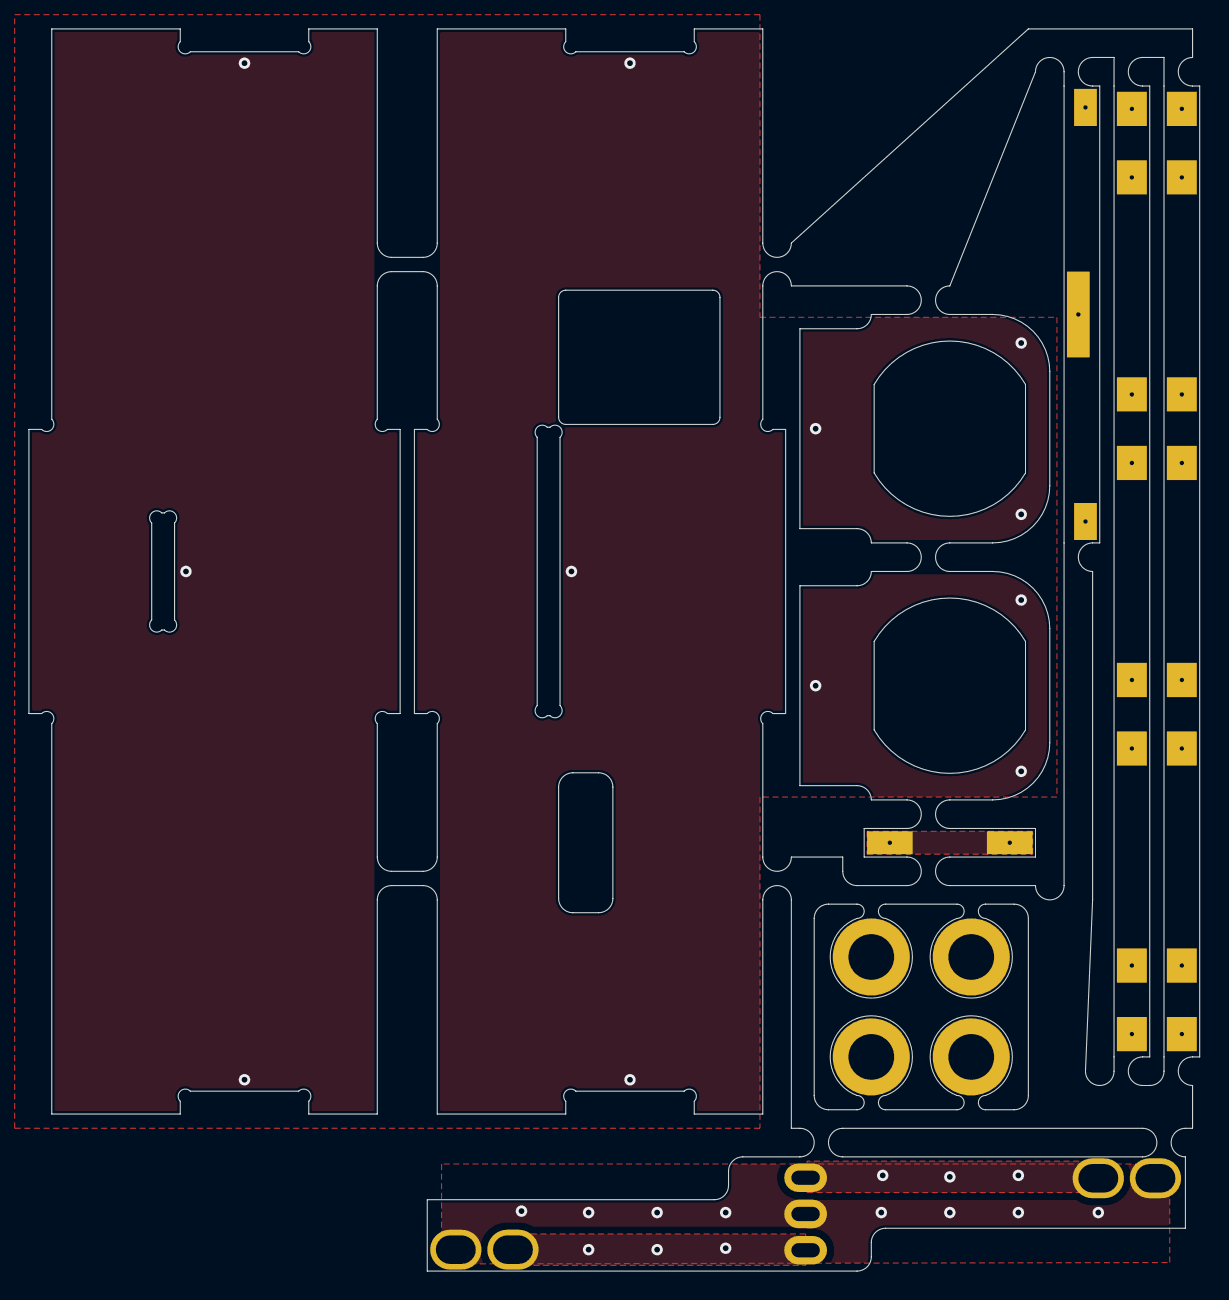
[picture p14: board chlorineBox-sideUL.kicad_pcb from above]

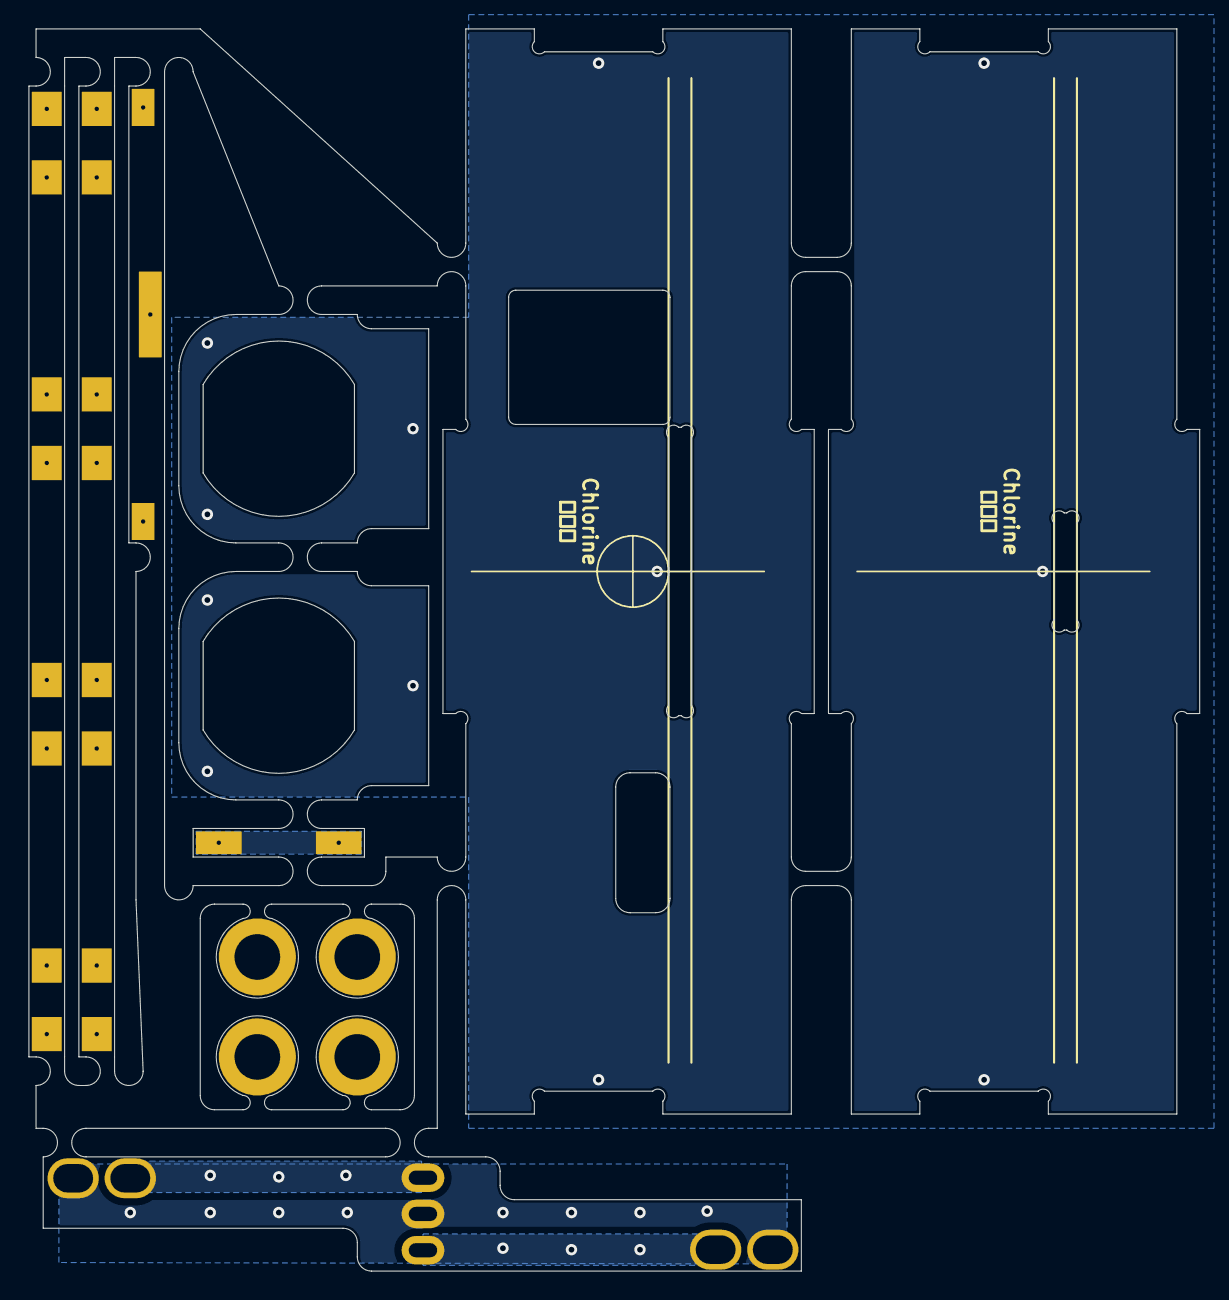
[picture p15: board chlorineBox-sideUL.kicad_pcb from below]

Board: 2 copper layers, 82.0 x 87.0 mm, 3 parts (3 on the bottom side), 3 nets, no tracks yet.

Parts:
J143: SWpin; PinHeader_1x03_P2.54mm_Vertical
SW5, SW6: sw; my_conn

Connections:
GND: J143.2, SW5.2, SW6.2
unnamed: J143.1, SW6.1
unnamed: J143.3, SW5.1

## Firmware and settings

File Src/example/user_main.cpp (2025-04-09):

#include "common.h"
#include "user_main.h"
#include "main.h"
#include "display.hpp"
#include "fx.hpp"
#include "eeprom.hpp"

extern SAI_HandleTypeDef hsai_BlockA1;
extern SAI_HandleTypeDef hsai_BlockB1;
extern TIM_HandleTypeDef htim1;
extern UART_HandleTypeDef huart3;

// DMA用バッファ配列 RAM_D2に置く
#define __ATTR_RAM_D2  __attribute__ ((section(".RAM_D2"))) __attribute__ ((aligned (4)))
int32_t RxBuffer[BLOCK_SIZE*4] __ATTR_RAM_D2 = {}; // 音声信号受信バッファ配列 Lch前半 Lch後半 Rch前半 Rch後半
int32_t TxBuffer[BLOCK_SIZE*4] __ATTR_RAM_D2 = {}; // 音声信号送信バッファ配列

uint32_t callbackCount = 0; // I2Sの割り込みごとにカウントアップ タイマとして利用
extern uint32_t cpuUsageCycleMax[]; // CPU使用サイクル数
const float i2sInterruptInterval = (float)BLOCK_SIZE / SAMPLING_FREQ; // I2Sの割り込み間隔時間

// スイッチ短押し、スイッチ長押し、ステータス情報表示時間のカウント数
const uint32_t shortPushCount = 1 + SHORT_PUSH_MSEC / (8 * 1000 * i2sInterruptInterval); // 1つのスイッチは8回に1回の読取のため8をかける
const uint32_t longPushCount = 1 + LONG_PUSH_MSEC / (8 * 1000 * i2sInterruptInterval);
const uint32_t statusDispCount = 1 + STATUS_DISP_MSEC / (1000 * i2sInterruptInterval);

bool fxOn = false; // エフェクトオン・オフ状態
bool exOn = false; // EX機能オン・オフ状態
string fxName = ""; // 現在のエフェクト名 11文字まで
string fxExFuncName = "TAP TEMPO"; // 現在のエフェクトのEX機能名 9文字まで
uint16_t fxColor = 0; // 現在のエフェクトLED色 RGB565
string fxParamName[20] = {}; // エフェクトパラメータ名 LEVEL, GAIN等
int16_t fxParam[20] = {}; // 現在のエフェクトパラメータ数値
string fxParamStr[20] = {}; // 現在のエフェクトパラメータ数値 文字列
int16_t fxParamMax[20] = {}; // エフェクトパラメータ最大値
int16_t fxParamMin[20] = {}; // エフェクトパラメータ最小値

//uint8_t fxParamNum = 0; // エフェクトパラメータ 現在何番目か ※0から始まる
uint8_t fxParamNumMax = 0; // エフェクトパラメータ数 最大値
uint8_t fxPage = 0; // エフェクトパラメータページ番号

uint8_t fxNum = 0; // 現在のエフェクト番号 ※0から始まる
int8_t fxChangeFlag = 0; // エフェクト種類変更フラグ 次エフェクトへ: 1 前エフェクトへ: -1

// 処理が重いエフェクトの場合、画面描画が遅くなる→画面描画が完了するまでエフェクトが切り替わらないようにする
uint8_t fxDispCpltFlag = 0; // エフェクト画面描画完了フラグ メインループ2回でエフェクト切替可能

string statusStr = PEDAL_NAME; // ステータス表示文字列

float tapTime = 0.0f; // タップテンポ入力時間 ms

int8_t re[5] = {};      // ロータリーエンコーダの状態 5番目re[4]は予備
int8_t last_re[5] = {}; // 前回のロータリーエンコーダの状態

const uint8_t fxNameXY[2] = {0,0};   // エフェクト名 表示位置
const uint8_t fxPageXY[2] = {110,0}; // エフェクトパラメータ ページ 表示位置
const uint8_t statusXY[2] = {110,10}; // ステータス 表示位置
const uint16_t percentXY[2] = {140,0}; // 処理時間% 表示位置
const uint8_t fxParamNameXY[6][2] = {{0,20},{39,20},{79,20},{119,20},{0,0},{0,0}}; // エフェクトパラメータ名表示位置
const uint8_t fxParamBarXY[6][2] = {{0,32},{39,32},{79,32},{119,32},{0,0},{0,0}}; // エフェクトパラメータバー表示位置
const uint8_t fxParamStrXY[6][2]  = {{2,49},{41,49},{81,49},{121,49},{0,0},{0,0}}; // エフェクトパラメータ数値表示 左端の文字位置

const uint8_t exFuncXY[2] = {9, 87}; // EX機能名称 表示位置
const uint8_t tapmsXY[2] = {69,87}; // タップテンポ ms 表示位置
const uint8_t tapbpmXY[2] = {111,87}; // タップテンポ bpm 表示位置

uint8_t clipDetect[4] = {}; // 入出力クリップ検出用 Lin Rin Lout Rout

bool saveDataFlag = false; // データ保存実行フラグ

uint16_t brightness[11] = {32,45,64,91,128,181,256,362,512,724,1024}; // LCD 明るさ
int8_t brightnessNum = 10; // LCD 明るさ段階数値 0～10

uint8_t midiRecievedBuf; // MIDI受信バッファ

void loadScreen() // 画面固定部分表示
{
  ST7735_FillScreen(ST7735_BLACK);

  // パラメーターバー枠表示
  for (int i = 0; i < 4; i++) ST7735_DrawLineX(40*i, 38+40*i, 32, ST7735_WHITE);
  for (int i = 0; i < 4; i++) ST7735_DrawLineX(40*i, 38+40*i, 46, ST7735_WHITE);
  for (int i = 0; i < 4; i++) ST7735_DrawLineY(0+40*i, 33, 45, ST7735_WHITE);
  for (int i = 0; i < 4; i++) ST7735_DrawLineY(38+40*i, 33, 45, ST7735_WHITE);

  // EX機能 枠表示
  ST7735_WriteString(9, 72, "EXTRA FUNCTION", Font_7x10, ST7735_WHITE, ST7735_BLACK);
  ST7735_DrawLineX(4, 7, 76, ST7735_WHITE);
  ST7735_DrawLineX(95, 154, 76, ST7735_WHITE);
  ST7735_DrawLineX(4, 154, 104, ST7735_WHITE);
  ST7735_DrawLineY(3, 77, 103, ST7735_WHITE);
  ST7735_DrawLineY(155, 77, 103, ST7735_WHITE);

  // ボタン名表示
  ST7735_WriteString(9, 115, "<FX", Font_7x10, ST7735_WHITE, ST7735_BLACK);
  ST7735_WriteString(49, 115, ">FX", Font_7x10, ST7735_WHITE, ST7735_BLACK);
  ST7735_WriteString(87, 115, "SAVE", Font_7x10, ST7735_WHITE, ST7735_BLACK);
  ST7735_WriteString(127, 115, "PAGE", Font_7x10, ST7735_WHITE, ST7735_BLACK);

  // ボタン枠表示
  for (int i = 0; i < 4; i++) ST7735_DrawLineX(2+40*i, 36+40*i, 110, ST7735_WHITE);
  for (int i = 0; i < 4; i++) ST7735_DrawLineX(2+40*i, 36+40*i, 127, ST7735_WHITE);
  for (int i = 0; i < 4; i++) ST7735_DrawLineY(1+40*i, 111, 126, ST7735_WHITE);
  for (int i = 0; i < 4; i++) ST7735_DrawLineY(37+40*i, 111, 126, ST7735_WHITE);
}

void dispBar(uint8_t i, int16_t param, int16_t min, int16_t max) // エフェクトパラメータバー表示
{
  uint8_t bar;

  // 割合を計算 ※ゼロ除算を除外
  if (max - min != 0) bar = 37 * (param - min) / (max- min);
  else bar = 0;

  for (int j = 33; j <= 45; j++)
  {
    ST7735_DrawLineX(40*i + 1, 40*i + bar, j, fxColor);
    ST7735_DrawLineX(40*i + bar + 1, 40*i + 37, j, ST7735_BLACK);
  }
}

void mainInit() // <<<<<<<<<<<<<<<<<<<<<<<<<<<<<<<<<<<<<<<<<<<最初に1回のみ行う処理
{
  // Denormalized numbers（非正規化数）を0として扱うためFPSCRレジスタ変更
  asm("VMRS r0, FPSCR");
  asm("ORR r0, r0, #(1 << 24)");
  asm("VMSR FPSCR, r0");

  // 処理時間計測用設定
  CoreDebug->DEMCR |= CoreDebug_DEMCR_TRCENA_Msk;
  DWT->CTRL |= DWT_CTRL_CYCCNTENA_Msk;

  // ディスプレイ初期化
  ST7735_Init();
  ST7735_FillScreen(ST7735_BLACK);

  // LCDバックライト PWM開始
  HAL_TIM_PWM_Start(&htim1, TIM_CHANNEL_4);
  __HAL_TIM_SET_COMPARE(&htim1, TIM_CHANNEL_4, 0);

  // 起動時左フットスイッチ、左下スイッチ、右下スイッチを押していた場合、データ全消去
  if (!HAL_GPIO_ReadPin(SW0_GPIO_Port, SW0_Pin) &&
      !HAL_GPIO_ReadPin(SW3_GPIO_Port, SW3_Pin) &&
      !HAL_GPIO_ReadPin(SW4_GPIO_Port, SW4_Pin))
  {
    ST7735_FillScreen(ST7735_BLACK);
    ST7735_WriteString(0, 0, "ERASE ALL DATA", Font_7x10, ST7735_WHITE, ST7735_BLACK);
    eraseData();
    HAL_Delay(1000);
  }

  // 保存済パラメータ読込
  loadData();
  __HAL_TIM_SET_COMPARE(&htim1, TIM_CHANNEL_4, 1024 - brightness[brightnessNum]);

  // 初期エフェクト読込 ※信号処理が始まる前にメモリ確保
  fxInit();

  // 起動時右フットスイッチを押し続けている間、明るさ調整
  while (!HAL_GPIO_ReadPin(SW5_GPIO_Port, SW5_Pin))
  {
    HAL_Delay(100);
    if (!HAL_GPIO_ReadPin(SW3_GPIO_Port, SW3_Pin)) brightnessNum++;
    if (!HAL_GPIO_ReadPin(SW0_GPIO_Port, SW0_Pin)) brightnessNum--;
    brightnessNum = clip(brightnessNum, 0, 10);
    __HAL_TIM_SET_COMPARE(&htim1, TIM_CHANNEL_4, 1024 - brightness[brightnessNum]);
    string tmpStr = "BRIGHTNESS:" + std::to_string(brightnessNum);
    if (brightnessNum < 10) tmpStr.insert(11, "0");
    ST7735_WriteString(10, 10, tmpStr, Font_11x18, ST7735_WHITE, ST7735_BLACK);
    saveDataFlag = true;
  }

  // 明るさデータを保存
  if (saveDataFlag)
  {
    saveDataFlag = false;
    saveData();
    ST7735_WriteString(10, 50, "BRIGHTNESS DATA STORED!", Font_7x10, ST7735_WHITE, ST7735_BLACK);
    HAL_Delay(1000);
  }

  // コーデック設定  M0 PB8 SET  M1 PB9 RESET
  HAL_GPIO_WritePin(M0_GPIO_Port, M0_Pin, GPIO_PIN_SET);
  HAL_GPIO_WritePin(M1_GPIO_Port, M1_Pin, GPIO_PIN_RESET);

  // SAIのDMA開始
  HAL_SAI_Receive_DMA(&hsai_BlockA1, (uint8_t*)RxBuffer, BLOCK_SIZE*4);
  HAL_SAI_Transmit_DMA(&hsai_BlockB1, (uint8_t*)TxBuffer, BLOCK_SIZE*4);

  // オーディオコーデック リセット
  HAL_GPIO_WritePin(CODEC_RST_GPIO_Port, CODEC_RST_Pin, GPIO_PIN_RESET);
  HAL_Delay(100);
  HAL_GPIO_WritePin(CODEC_RST_GPIO_Port, CODEC_RST_Pin, GPIO_PIN_SET);
  HAL_Delay(100);

  // I2Sのフレームエラー発生の場合、リセットを繰り返す
  while(__HAL_SAI_GET_FLAG(&hsai_BlockA1, SAI_FLAG_AFSDET)
     || __HAL_SAI_GET_FLAG(&hsai_BlockA1, SAI_FLAG_LFSDET)
     || __HAL_SAI_GET_FLAG(&hsai_BlockB1, SAI_FLAG_AFSDET)
     || __HAL_SAI_GET_FLAG(&hsai_BlockB1, SAI_FLAG_LFSDET))
  {
    ST7735_WriteString(0, 0, "ERROR", Font_11x18, ST7735_WHITE, ST7735_BLACK);
    HAL_GPIO_WritePin(CODEC_RST_GPIO_Port, CODEC_RST_Pin, GPIO_PIN_RESET);
    HAL_Delay(100);
    HAL_GPIO_WritePin(CODEC_RST_GPIO_Port, CODEC_RST_Pin, GPIO_PIN_SET);
    HAL_Delay(100);
  }

  // MIDI受信開始
  HAL_UART_Receive_IT(&huart3, &midiRecievedBuf,1);

  // 画面固定表示部分の描画
  loadScreen();

}

void mainLoop() // <<<<<<<<<<<<<<<<<<<<<<<<<<<<<<<<<<<<<<<<<<<メインループ
{
  // 前回の変数を記録しておき、変更があった時のみ描画する
  static string last_fxParamStr[20] = {};
  static uint8_t last_fxPage = 222;
  static uint8_t last_cpuUsagePercent = 111;
  static uint8_t last_fxNum = 123;

  // ページ切替、エフェクト切替時の画面再描画
  if (fxNum != last_fxNum || fxPage != last_fxPage)
  {
    // エフェクト名称表示
    ST7735_WriteString(fxNameXY[0], fxNameXY[1], paddingLeft(fxName, 11), Font_11x18, ST7735_WHITE, ST7735_BLACK);

    for (int i = 0; i < 4; i++)
    { // エフェクトパラメータ名称表示
      ST7735_WriteString(fxParamNameXY[i][0], fxParamNameXY[i][1], paddingLeft(fxParamName[i+4*fxPage], 6), Font_7x10, ST7735_WHITE, ST7735_BLACK);

      // エフェクトパラメータ数値表示
      fxSetParamStr(i+4*fxPage); // パラメータ数値を文字列に変換
      ST7735_WriteStringNarrow(fxParamStrXY[i][0], fxParamStrXY[i][1], paddingRight(fxParamStr[i+4*fxPage], 4), Font_11x18, ST7735_WHITE, ST7735_BLACK);

      // バー表示
      dispBar(i, fxParam[i+4*fxPage], fxParamMin[i+4*fxPage], fxParamMax[i+4*fxPage]);
    }

    // EX機能 名称表示
    ST7735_WriteString(exFuncXY[0], exFuncXY[1], paddingRight(fxExFuncName, 9), Font_7x10, ST7735_WHITE, ST7735_BLACK);
    ST7735_FillRectangleFast(tapmsXY[0], tapmsXY[1]-7, 84, 24, ST7735_BLACK);

    // エフェクトパラメータページ番号表示
    string fxPageStr = "P" + std::to_string(fxPage + 1) + "/" + std::to_string((fxParamNumMax-1) / 4 + 1);
    ST7735_WriteString(fxPageXY[0], fxPageXY[1], fxPageStr, Font_7x10, ST7735_WHITE, ST7735_BLACK);

    last_fxPage = fxPage;
    last_fxNum = fxNum;
  }

  // ステータス表示 ------------------------------
  static bool statusChangeStart = false; // ステータス表示変更開始フラグ

  if (statusStr != " ")
  {
    if (!statusChangeStart) // ステータス表示変更開始処理
    {
      callbackCount = 0;
      statusChangeStart = true;
    }

    if (callbackCount > statusDispCount) // 一定時間経過後、空白に戻す
    {
      ST7735_WriteString(statusXY[0], statusXY[1], "        ", Font_7x10, ST7735_WHITE, ST7735_BLACK);
      statusChangeStart = false;
      statusStr = " ";
    }
    else if ((callbackCount / (statusDispCount/6)) % 2 == 0) // 一定時間経過まで点滅
    {
      ST7735_WriteString(statusXY[0], statusXY[1], paddingLeft(statusStr, 8), Font_7x10, ST7735_WHITE, ST7735_BLACK);
    }
    else
    {
      ST7735_WriteString(statusXY[0], statusXY[1], "        ", Font_7x10, ST7735_WHITE, ST7735_BLACK);
    }
  }

  // エフェクトパラメータ数値表示------------------------------
  for (int i = 0; i < 4; i++)
  {
    fxSetParamStr(i+4*fxPage); // パラメータ数値を文字列に変換
    if (last_fxParamStr[i+4*fxPage] != fxParamStr[i+4*fxPage])
    {
      ST7735_WriteStringNarrow(fxParamStrXY[i][0], fxParamStrXY[i][1], paddingRight(fxParamStr[i+4*fxPage], 4), Font_11x18, ST7735_WHITE, ST7735_BLACK);
      last_fxParamStr[i+4*fxPage] = fxParamStr[i+4*fxPage];
      dispBar(i, fxParam[i+4*fxPage], fxParamMin[i+4*fxPage], fxParamMax[i+4*fxPage]); // バー表示
    }
  }

  // ロータリーエンコーダスイッチ押下時 エフェクトパラメータ下線表示------------------------------
  if (!HAL_GPIO_ReadPin(SW6_GPIO_Port, SW6_Pin)) ST7735_DrawLineX(0, 38, 66, ST7735_WHITE);
  else ST7735_DrawLineX(0, 38, 66, ST7735_BLACK);
  if (!HAL_GPIO_ReadPin(SW7_GPIO_Port, SW7_Pin)) ST7735_DrawLineX(40, 78, 66, ST7735_WHITE);
  else ST7735_DrawLineX(40, 78, 66, ST7735_BLACK);
  if (!HAL_GPIO_ReadPin(SW8_GPIO_Port, SW8_Pin)) ST7735_DrawLineX(80, 118, 66, ST7735_WHITE);
  else ST7735_DrawLineX(80, 118, 66, ST7735_BLACK);
  if (!HAL_GPIO_ReadPin(SW9_GPIO_Port, SW9_Pin)) ST7735_DrawLineX(120, 158, 66, ST7735_WHITE);
  else ST7735_DrawLineX(120, 158, 66, ST7735_BLACK);

  // CPU使用率表示------------------------------
  uint8_t cpuUsagePercent = 100.0f * cpuUsageCycleMax[fxNum] / SystemCoreClock / i2sInterruptInterval;
  if (last_cpuUsagePercent != cpuUsagePercent)
  {
    string percentStr = std::to_string(cpuUsagePercent);
    ST7735_WriteString(percentXY[0], percentXY[1], paddingRight(percentStr, 2) + "%", Font_7x10, ST7735_WHITE, ST7735_BLACK);
    last_cpuUsagePercent = cpuUsagePercent;
  }

  // EX機能表示------------------------------
  if (fxExFuncName == "TAP TEMPO")
  {
    string tmpStr = std::to_string((uint16_t)tapTime);
    ST7735_WriteString(tapmsXY[0], tapmsXY[1], paddingRight(tmpStr, 4) + "ms", Font_7x10, ST7735_WHITE, ST7735_BLACK); // タップ間隔時間を表示
    if (tapTime > 60.0f) tmpStr = std::to_string((uint16_t)(60000.0f / tapTime)); // bpmを計算
    ST7735_WriteString(tapbpmXY[0], tapbpmXY[1], paddingRight(tmpStr, 3) + "bpm", Font_7x10, ST7735_WHITE, ST7735_BLACK); // bpm表示

    uint16_t blinkCount = 1 + tapTime / (1000 * i2sInterruptInterval); // 点滅用カウント数
    if (callbackCount % blinkCount < 60 / (1000 * i2sInterruptInterval)) // 60msバーを表示、点滅
    {
      ST7735_DrawLineX(tapbpmXY[0], tapbpmXY[0] + 36, tapbpmXY[1] + 10, ST7735_WHITE);
      ST7735_DrawLineX(tapbpmXY[0], tapbpmXY[0] + 36, tapbpmXY[1] + 11, ST7735_WHITE);
    }
    else
    {
      ST7735_DrawLineX(tapbpmXY[0], tapbpmXY[0] + 36, tapbpmXY[1] + 10, ST7735_BLACK);
      ST7735_DrawLineX(tapbpmXY[0], tapbpmXY[0] + 36, tapbpmXY[1] + 11, ST7735_BLACK);
    }
  }
  else
  {
    if (exOn) // EX機能 ON表示
    {
      ST7735_DrawLineX(tapmsXY[0]+32, tapmsXY[0] + 70, tapmsXY[1]-7, fxColor);
      ST7735_DrawLineX(tapmsXY[0]+31, tapmsXY[0] + 71, tapmsXY[1]-6, fxColor);
      ST7735_DrawLineX(tapmsXY[0]+31, tapmsXY[0] + 71, tapmsXY[1]-5, fxColor);
      ST7735_WriteString(tapmsXY[0]+31, tapmsXY[1]-4, " ON ", Font_11x18, ST7735_BLACK, fxColor);
      ST7735_DrawLineX(tapmsXY[0]+32, tapmsXY[0] + 70, tapmsXY[1]+14, fxColor);
    }
    else // EX機能 OFF表示
    {
      ST7735_DrawLineX(tapmsXY[0]+32, tapmsXY[0] + 70, tapmsXY[1]-7, ST7735_COLOR565(80, 80, 80));
      ST7735_DrawLineX(tapmsXY[0]+31, tapmsXY[0] + 71, tapmsXY[1]-6, ST7735_COLOR565(80, 80, 80));
      ST7735_DrawLineX(tapmsXY[0]+31, tapmsXY[0] + 71, tapmsXY[1]-5, ST7735_COLOR565(80, 80, 80));
      ST7735_WriteString(tapmsXY[0]+36, tapmsXY[1]-4, "OFF", Font_11x18, ST7735_BLACK, ST7735_COLOR565(80, 80, 80));
      ST7735_DrawLineX(tapmsXY[0]+32, tapmsXY[0] + 70, tapmsXY[1]+14, ST7735_COLOR565(80, 80, 80));
      for (int i = 0; i < 5; i++) ST7735_DrawLineY(tapmsXY[0]+31+i, tapmsXY[1]-4, tapmsXY[1]+13, ST7735_COLOR565(80, 80, 80));
      for (int i = 0; i < 5; i++) ST7735_DrawLineY(tapmsXY[0]+67+i, tapmsXY[1]-4, tapmsXY[1]+13, ST7735_COLOR565(80, 80, 80));
    }
  }

  // 出力クリップ表示------------------------------
  uint8_t detect = clipDetect[0] << 3 | clipDetect[1] << 2 | clipDetect[2] << 1 | clipDetect[3];
  if (detect == 0b00001000) statusStr = "L i    ";
  if (detect == 0b00000100) statusStr = " Ri    ";
  if (detect == 0b00000010) statusStr = "    L o";
  if (detect == 0b00000001) statusStr = "     Ro";
  if (detect == 0b00001100) statusStr = "LRi    ";
  if (detect == 0b00001010) statusStr = "L i L o";
  if (detect == 0b00001001) statusStr = "L i  Ro";
  if (detect == 0b00000110) statusStr = " Ri L o";
  if (detect == 0b00000101) statusStr = " Ri  Ro";
  if (detect == 0b00000011) statusStr = "    LRo";
  if (detect == 0b00001011) statusStr = "L i LRo";
  if (detect == 0b00001101) statusStr = "LRi  Ro";
  if (detect == 0b00001110) statusStr = "LRi L o";
  if (detect == 0b00000111) statusStr = " Ri LRo";
  if (detect == 0b00001111) statusStr = "LRi LRo";

  // データ保存-----------------------------
  if (saveDataFlag)
  {
    saveDataFlag = false;
    saveData();
    statusStr = "STORED!";
  }

  // LED表示------------------------------
  uint8_t r = (fxColor >> 8) & 0b0000000011111000; // RGB565を変換 PWMで色を制御する場合使えるかも
  uint8_t g = (fxColor >> 3) & 0b0000000011111100;
  uint8_t b = (fxColor << 3) & 0b0000000011111000;
  if (r && fxOn) HAL_GPIO_WritePin(LED_R_GPIO_Port, LED_R_Pin, GPIO_PIN_SET);
  else HAL_GPIO_WritePin(LED_R_GPIO_Port, LED_R_Pin, GPIO_PIN_RESET);
  if (g && fxOn) HAL_GPIO_WritePin(LED_G_GPIO_Port, LED_G_Pin, GPIO_PIN_SET);
  else HAL_GPIO_WritePin(LED_G_GPIO_Port, LED_G_Pin, GPIO_PIN_RESET);
  if (b && fxOn) HAL_GPIO_WritePin(LED_B_GPIO_Port, LED_B_Pin, GPIO_PIN_SET);
  else HAL_GPIO_WritePin(LED_B_GPIO_Port, LED_B_Pin, GPIO_PIN_RESET);

  // ループ終了、ディスプレイ表示完了
  if (fxDispCpltFlag < 2) fxDispCpltFlag++;
}

void mute() // <<<<<<<<<<<<<<<<<<<<<<<<<<<<<<<<<<<<エフェクト切替時のミュート
{
  for (uint16_t i = 0; i < BLOCK_SIZE*4; i++)
  {
    TxBuffer[i] = 0;
  }
}

void fxChange() // <<<<<<<<<<<<<<<<<<<<<<<<<<<<<<<<<<<<<<<<<<<エフェクト変更
{
  mute();
  fxDeinit();
  fxNum = (fxNumMax + fxNum + fxChangeFlag) % fxNumMax; // 最大値←→最小値で循環
  fxPage = 0;
  fxInit();
  fxChangeFlag = 0;
  fxDispCpltFlag = 0;
}

void swProcess(uint8_t num) // <<<<<<<<<<<<<<<<<<<<<<<<<<<<<<<<<<<<<<<<<<<スイッチ処理
{
  static uint32_t swCount[10] = {}; // スイッチが押されている間カウントアップ

  switch(num)
  {
    case 0: // 左端スイッチ --------------------------------------------------------
      if (!HAL_GPIO_ReadPin(SW0_GPIO_Port, SW0_Pin))
      {
        swCount[num]++;
        if (swCount[num] == longPushCount) // 長押し 1回のみ動作
        {
          // 処理なし
        }
      }
      else
      {
        if (swCount[num] >= shortPushCount && swCount[num] < longPushCount) // 短押し 離した時の処理
        {
          if (fxDispCpltFlag > 1) fxChangeFlag = -1; // 前エフェクトへ
        }
        swCount[num] = 0;
      }
      break;
    case 1: // 左中スイッチ --------------------------------------------------------
      if (!HAL_GPIO_ReadPin(SW1_GPIO_Port, SW1_Pin))
      {
        swCount[num]++;
        if (swCount[num] == longPushCount) // 長押し 1回のみ動作
        {
          // 処理なし
        }
      }
      else
      {
        if (swCount[num] >= shortPushCount && swCount[num] < longPushCount) // 短押し 離した時の処理
        {
          if (fxDispCpltFlag > 1) fxChangeFlag = 1; // 次エフェクトへ
        }
        swCount[num] = 0;
      }
      break;
    case 2: // 右中スイッチ --------------------------------------------------------
      if (!HAL_GPIO_ReadPin(SW2_GPIO_Port, SW2_Pin))
      {
        swCount[num]++;
        if (swCount[num] == longPushCount) // 長押し 1回のみ動作
        {
          // 処理なし
        }
      }
      else
      {
        if (swCount[num] >= shortPushCount && swCount[num] < longPushCount) // 短押し 離した時の処理
        {
          saveDataFlag = true; // データ保存
        }
        swCount[num] = 0;
      }
      break;
    case 3: // 右端スイッチ --------------------------------------------------------
      if (!HAL_GPIO_ReadPin(SW3_GPIO_Port, SW3_Pin))
      {
        swCount[num]++;
        if (swCount[num] == longPushCount) // 長押し 1回のみ動作
        {
          // 処理なし
        }
      }
      else
      {
        if (swCount[num] >= shortPushCount && swCount[num] < longPushCount) // 短押し 離した時の処理
        {
          fxPage++; // ページ切替
          if (fxPage > (fxParamNumMax-1) / 4) fxPage = 0;
        }
        swCount[num] = 0;
      }
      break;
    case 4: // 左端上スイッチ --------------------------------------------------------
      if (!HAL_GPIO_ReadPin(SW6_GPIO_Port, SW6_Pin))
      {
        swCount[num]++;
        if (swCount[num] == longPushCount) // 長押し 1回のみ動作
        {
          // 処理なし
        }
      }
      else
      {
        if (swCount[num] >= shortPushCount && swCount[num] < longPushCount) // 短押し 離した時の処理
        {
          // 処理なし
        }
        swCount[num] = 0;
      }
      break;
    case 5: // 左中上スイッチ --------------------------------------------------------
      if (!HAL_GPIO_ReadPin(SW7_GPIO_Port, SW7_Pin))
      {
        swCount[num]++;
        if (swCount[num] == longPushCount) // 長押し 1回のみ動作
        {
          // 処理なし
        }
      }
      else
      {
        if (swCount[num] >= shortPushCount && swCount[num] < longPushCount) // 短押し 離した時の処理
        {
          // 処理なし
        }
        swCount[num] = 0;
      }
      break;
    case 6: // 右中上スイッチ --------------------------------------------------------
      if (!HAL_GPIO_ReadPin(SW8_GPIO_Port, SW8_Pin))
      {
        swCount[num]++;
        if (swCount[num] == longPushCount) // 長押し 1回のみ動作
        {
          // 処理なし
        }
      }
      else
      {
        if (swCount[num] >= shortPushCount && swCount[num] < longPushCount) // 短押し 離した時の処理
        {
          // 処理なし
        }
        swCount[num] = 0;
      }
      break;
    case 7: // 右端上スイッチ --------------------------------------------------------
      if (!HAL_GPIO_ReadPin(SW9_GPIO_Port, SW9_Pin))
      {
        swCount[num]++;
        if (swCount[num] == longPushCount) // 長押し 1回のみ動作
        {
          // 処理なし
        }
      }
      else
      {
        if (swCount[num] >= shortPushCount && swCount[num] < longPushCount) // 短押し 離した時の処理
        {
          // 処理なし
        }
        swCount[num] = 0;
      }
      break;
    default:
      break;
  }

}

void footSwProcess0() // <<<<<<<<<<<<<<<<<<<<<<<<<<<<<<<<<<<<<<<<<<<左フットスイッチ処理
{
  static uint32_t footSwCount = 0; // スイッチが押されている間カウントアップ

  if (!HAL_GPIO_ReadPin(SW4_GPIO_Port, SW4_Pin))
  {
    footSwCount++;
    if (footSwCount == 8*longPushCount) // 長押し
    {
      // 処理なし
    }
    if (footSwCount == 24*longPushCount) // 3倍長押し
    {
      // 処理なし
    }
  }
  else
  {
    if (footSwCount >= 8*shortPushCount && footSwCount < 8*longPushCount) // 短押し 離した時の処理
    {
      fxOn = !fxOn; // エフェクト オン／オフ
    }
    footSwCount = 0;
  }

}

void footSwProcess1() // <<<<<<<<<<<<<<<<<<<<<<<<<<<<<<<<<<<<<<<<<<<右フットスイッチ処理
{
  static uint32_t footSwCount = 0; // スイッチが押されている間カウントアップ
  static float tmpTapTime = 0; // タップ間隔時間 一時保存用

  if (!HAL_GPIO_ReadPin(SW5_GPIO_Port, SW5_Pin))
  {
    footSwCount++;
    if (footSwCount == 8*shortPushCount) // スイッチを押した時のタップ間隔時間を記録
    {
      tmpTapTime = (float)callbackCount * i2sInterruptInterval * 1000.0f;
      callbackCount = 0;
    }
    if (footSwCount == 8*longPushCount) // 長押し
    {
      // 処理なし
    }
    if (footSwCount == 24*longPushCount) // 3倍長押し
    {
      // 処理なし
    }
  }
  else
  {
    if (footSwCount >= 8*shortPushCount && footSwCount < 8*longPushCount) // 短押し 離した時の処理
    {
      if (fxExFuncName == "TAP TEMPO")
      { // スイッチを押した時記録していたタップ間隔時間をスイッチを離した時に反映させる
        if (100.0f < tmpTapTime && tmpTapTime < MAX_TAP_TIME) tapTime = tmpTapTime;
        else tapTime = 0.0f;
      }
      else exOn = !exOn; // EX機能 オン／オフ
    }
    footSwCount = 0;
  }

}
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

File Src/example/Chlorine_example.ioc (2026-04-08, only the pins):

Mcu.UserName=STM32H723VGTx
PA13(JTMS/SWDIO).Signal=DEBUG_JTMS-SWDIO
PA14(JTCK/SWCLK).Signal=DEBUG_JTCK-SWCLK
PA15(JTDI).GPIO_Label=RE2B
PA15(JTDI).Signal=GPIO_Input
PA8.GPIO_Label=RE2A
PA8.Signal=GPIO_Input
PB10.Signal=I2C2_SCL
PB11.Signal=I2C2_SDA
PB13.Signal=SPI2_SCK
PB15.Signal=SPI2_MOSI
PB4(NJTRST).GPIO_Label=LED_G
PB4(NJTRST).Signal=GPIO_Output
PB5.GPIO_Label=RE0A
PB5.Signal=GPIO_Input
PB6.GPIO_Label=LED_R
PB6.Signal=GPIO_Output
PB7.GPIO_Label=RE0B
PB7.Signal=GPIO_Input
PB8.GPIO_Label=M0
PB8.Signal=GPIO_Output
PB9.GPIO_Label=M1
PB9.Signal=GPIO_Output
PC10.GPIO_Label=SW5
PC10.Signal=GPIO_Input
PC11.GPIO_Label=SW4
PC11.Signal=GPIO_Input
PC12.GPIO_Label=LED_B
PC12.Signal=GPIO_Output
PC6.GPIO_Label=SW9
PC6.Signal=GPIO_Input
PC7.GPIO_Label=RE3B
PC7.Signal=GPIO_Input
PC8.GPIO_Label=SW3
PC8.Signal=GPIO_Input
PC9.GPIO_Label=RE3A
PC9.Signal=GPIO_Input
PD0.GPIO_Label=SW2
PD0.Signal=GPIO_Input
PD1.GPIO_Label=SW8
PD1.Signal=GPIO_Input
PD13.GPIO_Label=LCD_RS
PD13.Signal=GPIO_Output
PD14.GPIO_Label=LCD_RES
PD14.Signal=GPIO_Output
PD15.GPIO_Label=LCD_CS
PD15.Signal=GPIO_Output
PD2.GPIO_Label=SW1
PD2.Signal=GPIO_Input
PD3.GPIO_Label=RE1A
PD3.Signal=GPIO_Input
PD4.GPIO_Label=SW7
PD4.Signal=GPIO_Input
PD5.GPIO_Label=RE1B
PD5.Signal=GPIO_Input
PD6.GPIO_Label=SW6
PD6.Signal=GPIO_Input
PD7.GPIO_Label=SW0
PD7.Signal=GPIO_Input
PD8.Signal=USART3_TX
PD9.Signal=USART3_RX
PE1.GPIO_Label=CODEC_RST
PE1.Signal=GPIO_Output
PE10.GPIO_Label=HARDWARE_VERSION0
PE10.Signal=GPIO_Input
PE11.GPIO_Label=HARDWARE_VERSION1
PE11.Signal=GPIO_Input
PE12.GPIO_Label=HARDWARE_VERSION2
PE12.Signal=GPIO_Input
PE13.GPIO_Label=HARDWARE_VERSION3
PE13.Signal=GPIO_Input
PE14.Signal=S_TIM1_CH4
PE2.Signal=SAI1_MCLK_A
PE3.Signal=SAI1_SD_B
PE4.Signal=SAI1_FS_A
PE5.Signal=SAI1_SCK_A
PE6.Signal=SAI1_SD_A
PH0-OSC_IN.Signal=RCC_OSC_IN
PH1-OSC_OUT.Signal=RCC_OSC_OUT

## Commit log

2025-04-11 Update Schematic
2025-04-26 Update Docs, KiCad
    [chlorineBox-acryl-Edge_Cuts.dxf, chlorineBox-bottom-sideL.kicad_pcb, chlorineBox-sideUL.kicad_pcb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]
